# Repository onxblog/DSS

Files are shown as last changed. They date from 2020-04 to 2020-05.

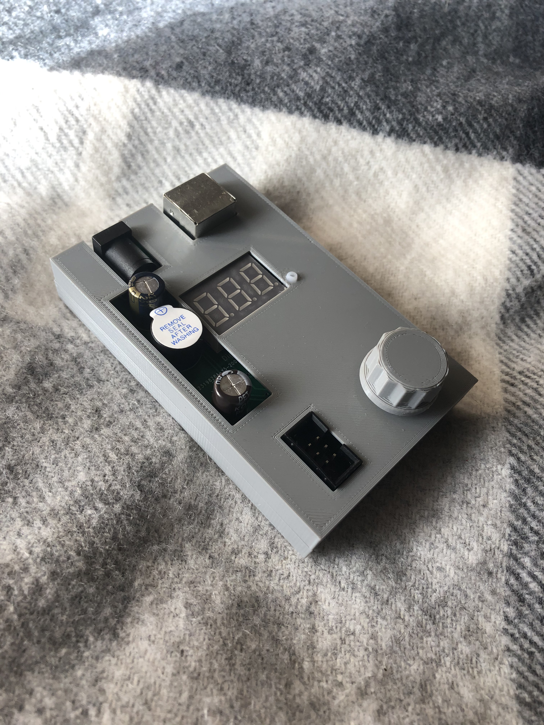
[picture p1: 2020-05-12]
Complit_images/IMG_0456.jpg

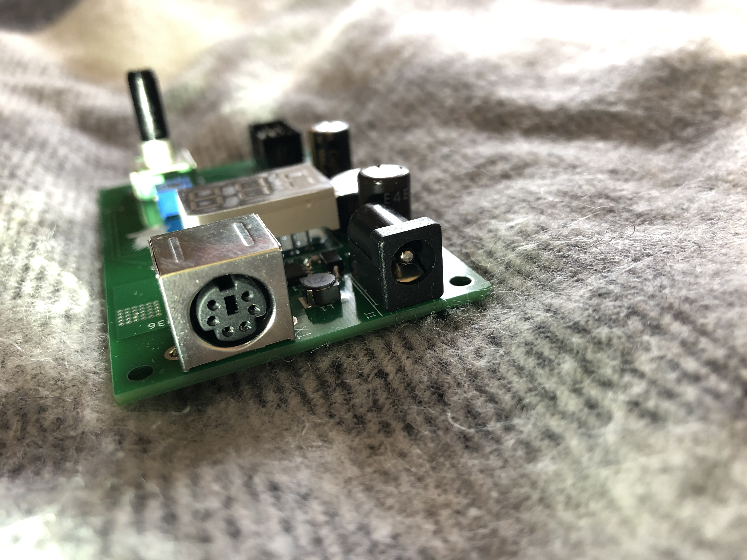
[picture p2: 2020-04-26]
Complit_images/3.jpg

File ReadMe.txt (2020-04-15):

### ----- Digital Soldering Station ----- ###

This station designed in Ukraine and in code have Ukrainian annotation.
Digital Soldering Station (next DSS) designed for iron solder HAKKO 936
Compatible with Lukey 868 852D+ 936+ irons and many others builded on ceramic HAKKO A1321 part.  
DSS have 3 digit led display, buzzer, soft start, programm detector activity, user profilies, encoder managment interface. 

SRC coded in CodeVisionAVR
Firmware autor Victor_P Ukraine

### --- Russian
Данная станция создавалась при участии форума радиокот.
Проект получился весьма интересным и очень качественным.
Дабы труды которые были потраченны на создание данной станции не были напрасны.
Я решил выложить исходные коды (любезно предоставленные Виктором П. во всеобщее пользование) 
и все имеющиеся у меня мои наработки по этой станции во всеобщее пользование.
Особая благодарность Виктору П. за разработку прошивки для данной станции.
Автор прошивки более не поддерживает эту версию станции, а занялся новым проектом совмещающим все имеющиеся у него наработки для создания
новой универсальной станции для всех типов паяльников. Поэтому дання версия отныне в руках GitHub комьюнити.
Версия платы разработанная мною в Eagle, расчитана на паяльники с разъемом вида PS2 от компании Lukey.
Рекомендую прочесть инструкцию, что бы увидеть какой огромный функционал имеет дання станция.
Данные паяльники HAKKO 936 по сей день остаются весьма популярны по причине дешевых расходников и наличия медных жал.
И довольно качесивенного 60Ват керамического нагревателя.

Технические характеристики: 
 Диапазон поддерживаемых температур – 80-420°C.
 Алгоритм нагрева – ПИ.
 Таймер дежурного режима и выключения – есть, совмещенный настраиваемый.
 Программный детектор активности паяльника – есть, настраиваемый.
 Количество профилей паяльников – 2.
 Количество предварительно установленных температур от 3 до 8, настраиваемые.
 Программная калибровка – есть.
 Плавный разогрев – есть.

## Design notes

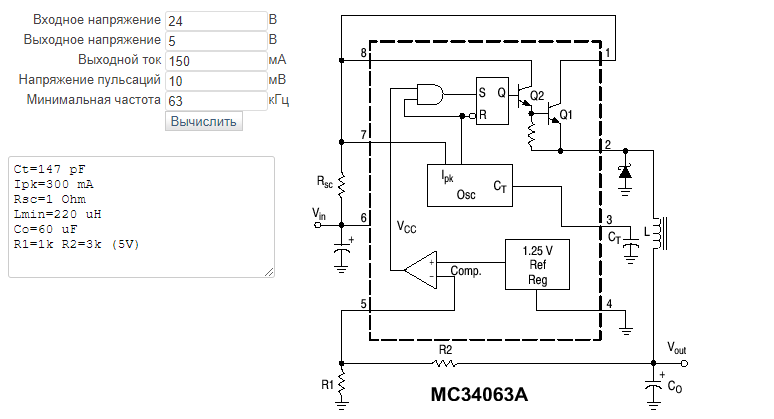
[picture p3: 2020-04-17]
MC34063A.png

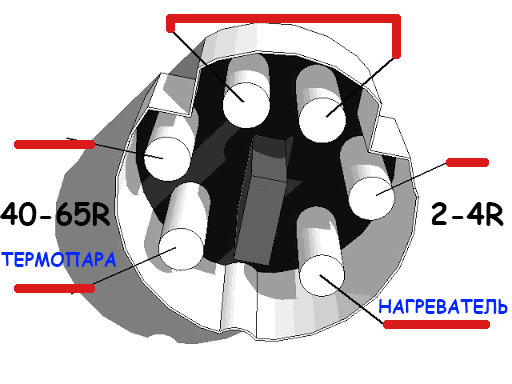
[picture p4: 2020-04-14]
Connector_Lukey_868_852D+_936+.png

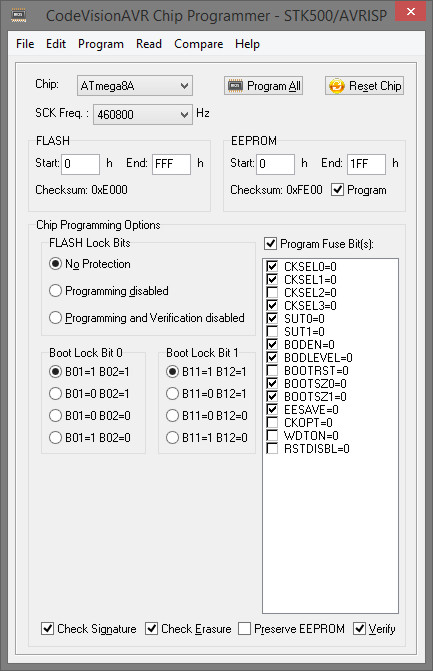
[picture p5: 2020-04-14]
Firmware_bin/fuses.jpg

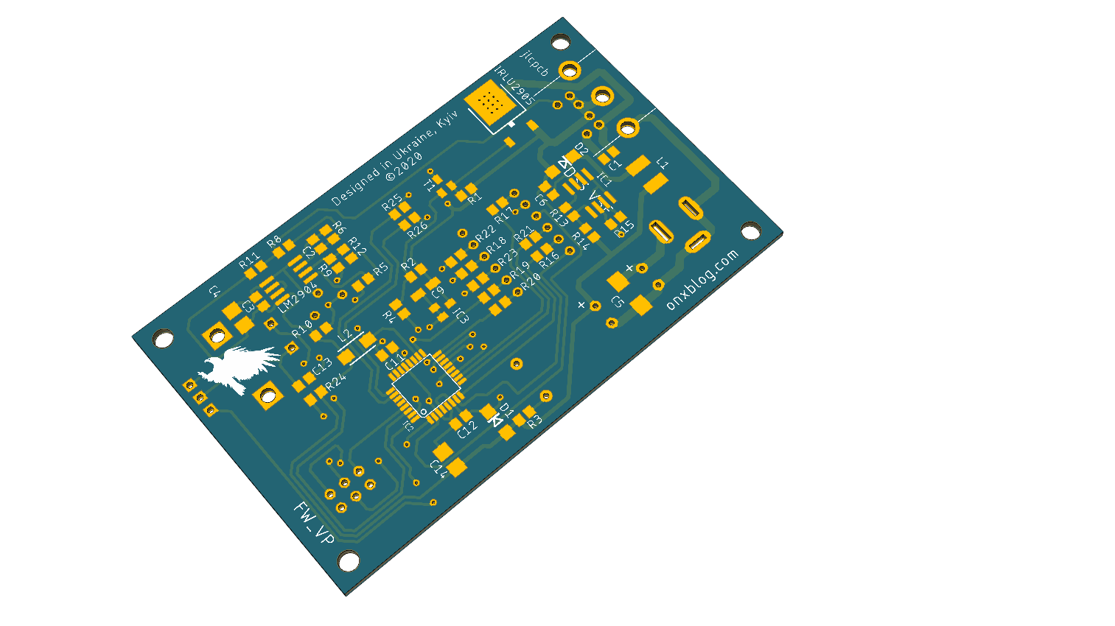
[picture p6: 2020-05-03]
Complit_images/board_img.png

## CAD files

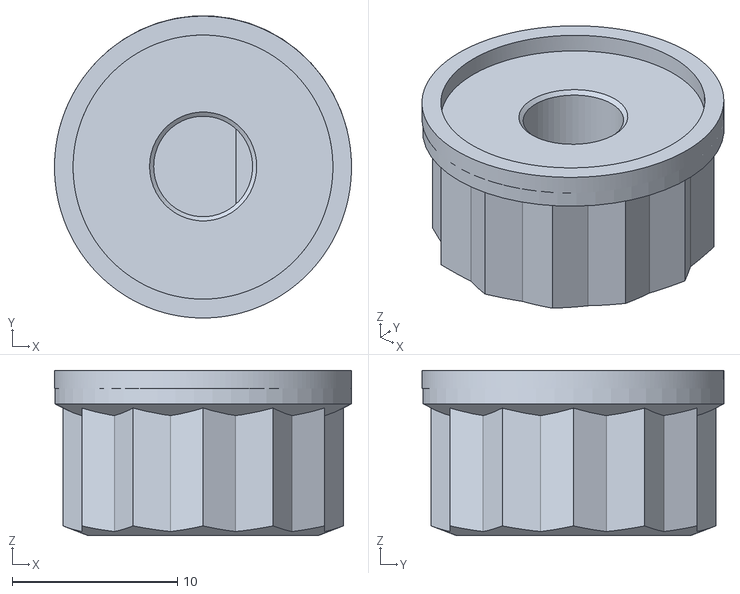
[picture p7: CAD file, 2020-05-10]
3D_Print_case/knob.stl
18.0 x 18.3 x 10.00

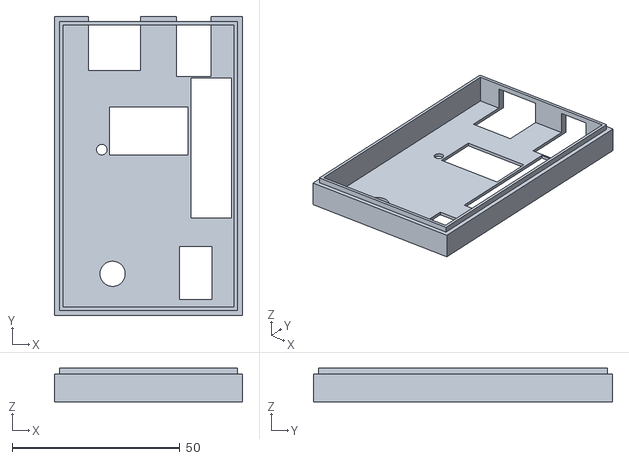
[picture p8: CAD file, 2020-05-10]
3D_Print_case/DSS_UP.stl
56.0 x 89.0 x 10.0

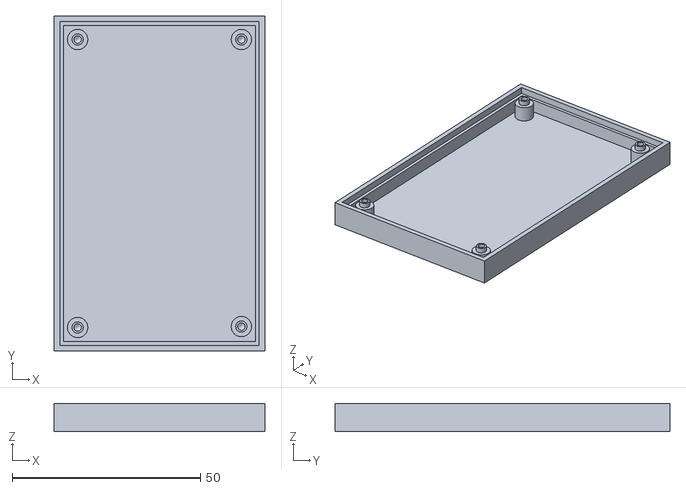
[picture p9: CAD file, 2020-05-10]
3D_Print_case/DSS_DOWN.stl
56.0 x 89.0 x 7.50

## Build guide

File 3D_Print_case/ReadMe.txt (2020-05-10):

Корпус с большим вырезом под конденсаторы и пищалку для разных вариантов плат.
В финале будут вырезы только под конденсаторы что бы сохранить толщину.
Возможен еще вариант без выреза если конденасторы SMD.
Защелки в корпусе не нужны, так как показала практика держится крепко и в таком варианте.

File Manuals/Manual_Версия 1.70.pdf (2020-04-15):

Короткая инструкция по эксплуатации (для версии 1.70, для предыдущих версий некоторые действия будут отличаться).

Внимание! Существует 2 версии этой прошивки, для управления энкодером и для управления кнопками. Не перепутайте нужный вариант при заливке! Версия ПО для управления кнопками мною (и на момент написания инструкции кем-либо еще) не тестировалась.

Управление энкодером:
При первом включении сработает автоопределение типа индикатора. В зависимости от его типа, на индикаторе высветится CAd или CCd при правильном определении типа, либо какой-то бред при неправильном. Если высветился тип индикатора,- нажимаем на энкодер, если высветился мусор,- крутим энкодер в любую сторону, при этом должен высветиться нужный тип и потом нажимаем на энкодер для подтверждения выбора.
- Режим [SM_MAIN_PRM] (первичный режим управления):
После выбора типа индикатора при первом включении и при каждом последующем включении станция 1,5 сек. показывает заданную температуру (изначально это 280 °C), после чего переходит в основной [SM_MAIN_PRM] режим и включает нагрев, светодиодный индикатор засветится красным •. После достижения заданной температуры +-1°C через 4 сек. станция перейдет в режим стабилизации (в котором будет пока температура не выйдет за диапазон установленная +-3°C), индикатор засветится зеленым •.
В зависимости от того, какой приоритетный режим управления выбран в меню настройки CtL, приоритет выбора пресетов температуры (P) или приоритет прямой регулировки температуры (t), вращением энкодера можно либо установить температуру в диапазоне от 80°C до 420°C с шагом в 5°C либо выбрать значение температуры из одного из пресетов, заданное значение автоматически примениться через 4 сек.
Длинным нажатием на энкодер можно записать выставленную температуру в текущую ячейку пресета.
Коротким нажатием на энкодер осуществится переход во вторичный режим управления
[SM_MAIN_SEC].
- Режим [SM_MAIN_SEC] (вторичный режим управления):
Аналогичный первичному, с той разницей, что если для первичного режима выбрано регулирование температуры, то во вторичном будет выбор из пресетов и наоборот.
Выбранное значение применится автоматически через 4 сек. (после чего станция вернется в режим [SM_MAIN_PRM]), или при коротком нажатии на энкодер (при этом также произойдет переход в режим установки времени таймера [SM_TMR_SET]).
Действие для длинного нажатия на кнопку энкодера аналогичное такому для режима
[SM_MAIN_PRM].

Не зависимо для какого режима назначено управление методом выбора пресетов, алгоритм его работы такой: при вращении ручки энкодера по часовой стрелке циклично перебираются активные пресеты температуры, при вращении ручки против часовой стрелки выбирается режим Stb затем OFF. Выбранные значения применятся автоматически через 4 сек.
Переход на следующий уровень меню при выбранных режимах Stb или OFF не производится.
- Режим [SM_TMR_SET] (установка времени таймера):
Вращением энкодера можно установить время срабатывания таймера в диапазоне 0 – 90 мин. С шагом 5 мин. 0 – таймер отключен. Выбранное значение применится автоматически через 4 сек. Коротким нажатием на энкодер значение также применится, но не запишется в EEPROM, т.е. применится только на текущий сеанс работы станции.
Длинное нажатие на энкодер даст тот-же эффект что и автоматическое применение значения через 4 сек.
После любого типа применения установленного значения времени таймера станция вернется в
режим [SM_MAIN_PRM].

- Режим настройки [SM_SUP]:
Вход в режим осуществляется при включении станции с нажатой кнопкой энкодера, при этом отобразится текущая версия программы, после отпускания кнопки появится мигающая надпись SEt. Выход из этого режима в режим [SM_MAIN_PRM] производится длинным нажатием на энкодер. Вращением энкодера влево/вправо (выбор закольцован) можно выбрать один из параметров (подменю) настройки:
- CLb – запуск калибровки, можно производить коротким или длинным нажатием кнопки энкодера;
- Htr – установка коэффициентов ПИД алгоритма нагрева, выбор частоты и максимального заполнения (%) ШИМ нагревателя;
- AdL – установка чувствительности детектора активности паяльника;
- CtL – выбор приоритетного управления и количества активных пресетов температуры;
- Sbt – установка температуры для ждущего режима.
Во всех параметрах настройки кроме CLb, изменение значения подтверждается коротким нажатием на энкодер (автоматический выход из параметра будет через 5 сек. без подтверждения изменения и соответственно без записи нового значения). В подменю Htr и CtL коротким нажатием также осуществляется переход к следующему значению.
- CLb
При запуске калибровки первый раз или при запуске длинным нажатием на энкодер значения коэффициентов начального смещения и усиления, которые передаются в функцию калибровки, будут дефолтными. Т.о. запускать процесс калибровки длинным нажатием на энкодер нужно, если необходимо произвести калибровку заново "с нуля".
При запуске калибровки коротким нажатием на энкодер коэффициенты смещения и усиления не сбрасываются, т.о. можно повторным запуском произвести "докалибровку" (более точную настройку) коэффициентов. Хотя смысла в этом особого нет.
При запуске калибровки на экране появится мигающая комнатная температура (текущая температура холодного паяльника) или сообщение об ошибке, если температура больше 50°C. Необходимо выставить ее верное значение и нажать на энкодер. Пойдет разогрев паяльника до 350°C после стабилизации этого значения индикатор начнет мигать, необходимо измерить реальную температуру паяльника, ввести это значение и нажать на энкодер.
- Htr
Можно установить последовательно коэффициенты ПИД P, I, D, частоту ШИМ Fr, максимальное заполнение ШИМ в % U. При выборе частоты работы ШИМ нагревателя (Fr) индикация частоты отображается в виде буквы H или L для 100Гц и 6.25Гц соответственно.
- CtL
Можно выбрать приоритетное управление (Pc) t – регулировка температуры, P – выбор пресетов и количество активных пресетов (Pn) от 3 до 8.
Выход из любого параметра настройки и калибровки будет в режим [SM_SUP] (SEt на индикаторе).

Управление кнопками:
При первом включении сработает автоопределение типа индикатора. В зависимости от его типа, на индикаторе высветится CAd или CCd при правильном определении типа, либо какой-то бред при неправильном. Если высветился тип индикатора,- нажимаем на "FUNC", если высветился мусор,-нажимаем "+" или "-", при этом должен высветиться нужный тип и потом нажимаем на "FUNC" для подтверждения выбора.
- Режим [SM_MAIN] (основной режим станции):
После выбора типа индикатора при первом включении и при каждом последующем включении станция 1,5 сек. показывает заданную температуру (изначально это 280 °C), после чего переходит в основной [SM_MAIN] режим и включает нагрев, светодиодный индикатор засветится красным •. После достижения заданной температуры +-1°C через 4 сек. станция перейдет в режим стабилизации (в котором будет пока температура не выйдет за диапазон установленная +-3°C), индикатор засветится зеленым •. Коротким нажатием на "+" или "-" можно выбрать одно из предварительно заданных значений температуры (пресетов). Выбранное значение автоматически примениться через 4 сек.

Длинным нажатием (удерживанием) "+" или "-" можно установить температуру в диапазоне от 80°C до 420°C. Первые пять значений регулируемого параметра будут переключаться медленно (задержка 200мс), все остальные (до отпускания кнопки) быстрее (задержка 40мс). Выбранное значение автоматически примениться через 4 сек.
Длинным нажатием на "FUNC" можно записать выставленную температуру в текущую ячейку пресета.
Коротким нажатием на "FUNC" осуществится переход в режим установки времени таймера
[SM_TMR_SET].
- Режим [SM_TMR_SET] (установка времени таймера):
Нажатием на "+" или "-" можно установить время срабатывания таймера в диапазоне 0 – 90 мин. 0 – таймер отключен. Выбранное значение применится автоматически через 4 сек и будет произведен выход в основной режим.
Длинное нажатие на кнопку "FUNC" даст тот-же эффект что и автоматическое применения. Короткое нажатие на кнопку "FUNC" сразу после входа в режим (если значение не изменялось) даст переход в режим настроек [SM_SUP].
- Режим настроек [SM_SUP]:
Вход в режим можно осуществить 2мя способами: при включении станции с нажатой кнопкой "FUNC" (при этом отобразится текущая версия программы), а также из режима [SM_TMR_SET]. При входе в режим появится мигающая надпись SEt. Выход из этого режима в режим [SM_MAIN] производится длинным нажатием на кнопку "FUNC".
Нажатием на "+" или "-" (выбор закольцован) можно выбрать один из параметров (подменю) настройки:
- CLb – запуск калибровки, можно производить коротким или длинным нажатием кнопки "FUNC";
- Htr – установка коэффициентов ПИД алгоритма нагрева, выбор частоты и максимального заполнения (%) ШИМ нагревателя;
- AdL – установка чувствительности детектора активности паяльника;
- Sbt – установка температуры для ждущего режима.
Во всех параметрах настройки кроме CLb, изменение значения подтверждается коротким нажатием на кнопку "FUNC" (автоматический выход из параметра будет через 4 сек. без подтверждения изменения и соответственно без записи нового значения). В подменю Htr коротким нажатием также осуществляется переход к следующему значению.
- CLb
При запуске калибровки первый раз или при запуске длинным нажатием на "FUNC" значения коэффициентов начального смещения и усиления, которые передаются в функцию калибровки, будут дефолтными. Т.о. запускать процесс калибровки длинным нажатием на "FUNC" нужно, если необходимо произвести калибровку заново "с нуля".
При запуске калибровки коротким нажатием на "FUNC" коэффициенты смещения и усиления не сбрасываются, т.о. можно повторным запуском произвести "докалибровку" (более точную настройку) коэффициентов. Хотя смысла в этом особого нет.
При запуске калибровки на экране появится мигающая комнатная температура (текущая температура холодного паяльника) или сообщение об ошибке, если температура больше 50°C. Необходимо выставить ее верное значение и нажать на "FUNC". Пойдет разогрев паяльника до 350°C после стабилизации этого значения индикатор начнет мигать, необходимо измерить реальную температуру паяльника, ввести это значение и нажать на "FUNC".
- Htr
Можно установить последовательно коэффициенты ПИД P, I, D, частоту ШИМ Fr, максимальное заполнение ШИМ в % U. При выборе частоты работы ШИМ нагревателя (Fr) индикация частоты отображается в виде буквы H или L для 100Гц и 6.25Гц соответственно.
Выход из любого параметра настройки и калибровки будет в режим [SM_SUP] (SEt на индикаторе).

Состояние ошибки:

В этом режиме отключается нагрев, станция не реагирует ни на какие действия с энкодером или кнопками, на индикаторе мигает надпись Err, светодиодный индикатор мигает зеленым и красным цветом ••, идет прерывистый звуковой сигнал. Выход из этого состояния возможен только автоматически при пропадании причин возникновения ошибки.
Ошибка может возникать по 2м причинам:
1. Превышение максимальной допустимой температуры (460°C), обычно это говорит об обрыве в цепи измерительного терморезистора или неисправности ОУ или его обвязки;
2. Температура не растет или не падает к заданной в течение 10 сек., может возникать при проблемах как в цепи нагревателя, так и в цепи измерения температуры.

Принцип работы таймера дежурного режима/отключения:
Таймер ведет обратный отсчет только если температура стабилизировалась (зеленый • св. диод). По истечении времени таймера станция перейдет в режим ожидания [SM_STB] (появится мигающая надпись Stb), в котором температура будет поддерживаться на уровне, установленном в меню Sbt. При достижении этой температуры и ее стабилизации (надпись Stb перестанет мигать) таймер запустится снова со значением времени в 2 раза большем выставленного. По истечении этого времени станция перейдет в режим [SM_OFF] (появится надпись OFF),- нагрев выключится. Возврат из режимов [SM_STB] и [SM_OFF] в режим [SM_MAIN] производится любым действием с энкодером (или нажатием на любую кнопку), при этом можно не бояться его крутнуть слишком сильно, изменения установленной температуры не произойдет до прекращения вращения.
Если таймер включен, то на индикаторе в младшем разряде светится точка.
Также таймер сбрасывается детектором активности паяльника (если он включен). Сброс таймера сигнализируется миганием точки в младшем разряде индикатора.

История:

Версия 1.70 (08.11.2014)
добавлено:
- динамическое ограничение максимального заполнения ШИМ;
изменено:
- убрана функция софтстарта (заменена на динамическое ограничение заполнения ШИМ);
- уменьшен выбор частот ШИМ до 2х: 6.25Гц и 100Гц;
- на 56мкс смещено начало АЦ преобразования;
исправлено:
- мелкий баг в управлении;

Версия 1.6 (25.04.2014)
добавлено:
- возможность устанавливать температуру ждущего режима;
- возможность выбирать количество активных пресетов температуры (от 3х до 8ми);
- возможность выбирать первичный тип управления станцией из 2х возможных:
- вращением ручки энкодера установка температуры, после короткого нажатия на энкодер выбор пресета (как было раньше до прошивки 1.5 включительно);
- вращением ручки энкодера выбор пресета, после короткого нажатия на энкодер установка температуры.
- новые пункты меню в режиме настроек;
- возможность принудительно перевести станцию в режим ожидания или выкл.
изменено:
- длительность софтстарта увеличена с 10 секунд до 12 (40 шагов по 300мс), максимальное заполнение ШИМ с 33% до 50%;
- максимальная температура, при которой включается софтстарт увеличена с 60°C до 65°C;
- подменю настройки PId и PFr объединены в одно Htr;
- много изменений в алгоритме управления;
исправлено:

- всякие мелочи;

Версия 1.5 (21.04.2014)
добавлено:
- при включении с нажатой кнопкой энкодера (входе в режим настроек) сначала отображается номер версии прошивки (при первом включении, если не верно определился тип индикатора, покажет мусор);
- выбор частоты ШИМ нагревателя из 3х вариантов: 15.625Гц, 62.5Гц, 250Гц;
изменено:
- температура в ждущем режиме увеличена до 120°C;
- период запуска ПИД алгоритма нагрева не синхронизирован с АЦ преобразованием и составляет 200мс;
- алгоритм измерения и отображения температуры;
- функция автоопределения типа индикатора;
- время перехода из ждущего режима в выкл. теперь в 2 раза больше установленного для перехода в ждущий режим;
- функция софтстарта, теперь софтстарт длится 10 сек (40 шагов по 250мкс);
- алгоритм индикации для разных типов индикаторов;
- в ШИМ нагревателя уменьшено количество ступеней регулировки с 1024 до 250; исправлено:
- проблема с калибровкой в версии 1.41;

Версия 1.41 (24.06.2013)
добавлено:
- вход в режим калибровки по длинному нажатию на энкодер (со сбросом калибровочных коэффициентов);
изменено:
- масштабы коэффициентов ПИД алгоритма нагрева;
исправлено:
- при включении станции показывается установленная температура, а не 000;
- убраны звуковые сигналы, которые могли возникать при определенных условиях, когда станция находилась в режиме калибровки после стабилизации "верхней" температуры 350°C.

Версия 1.4 (25.05.2013)
добавлено:
- сторожевая собака на 1с;
- подтверждение автовыбора типа индикатора коротким нажатием на энкодер и возможность задать вручную при ошибке автовыбора;
- параметр настройки AdL – чувствительность детектора активности паяльника 0-95 (большее значение – меньшая чувствительность, 0 - детектор выключен);
изменено:
- замеры температуры сделаны в перерывах между импульсами ШИМ нагревателя;
- полностью изменен ПИД алгоритм нагрева, применен дифференциальный вариант по совету и при поддержке Леонида Ивановича;
- полностью изменен детектор активности паяльника, применен алгоритм Леонида Ивановича;
- шаг изменения значения таймера изменен с 10 на 5 минут;
- таймер работает только в режиме стабилизации температуры (зеленый светодиод), во время нагрева/остывания нет;
- выход из любого параметра настройки (с сохранением – коротким нажатием, без сохранения – ждем 4с) происходит в режим настройки (SEt), выход из режима настройки теперь длинным нажатием на энкодер;
исправлено:
- убрана реакция на последнюю нажатую кнопку в режиме ошибки;
- теперь при переходе в режим установки времени таймера, если перед этим была выбрана температура из пресета, она таки выбирается;

- при длинном нажатии на энкодер в режиме выбора пресета или времени таймера теперь значение записывается, выбирается и производится выход в основной режим.

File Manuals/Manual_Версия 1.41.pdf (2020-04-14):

Короткая инструкция по эксплуатации (для версии 1.41, для предыдущих версий некоторые действия буду отличаться).

При первом включении сработает автоопределение типа индикатора. В зависимости от его типа, на индикаторе высветится CAd или CCd при правильном определении типа, либо какой-то бред при неправильном. Если высветился тип индикатора,- нажимаем на энкодер, если высветился мусор,- крутим энкодер (в любую сторону), при этом должен высветиться нужный тип и потом нажимаем на энкодер для подтверждения выбора.

- Режим [SM_MAIN] (основной):
После выбора типа индикатора при первом включении и при каждом последующем включении станция 1,5 сек. показывает заданную температуру (изначально это 280 °C), после чего переходит в основной [SM_MAIN] режим и включает нагрев (в зависимости от текущей температуры, если она меньше 60°C, включится софтстарт), св.диод засветится красным •. После достижения заданной температуры +-1°C через 4 сек. станция перейдет в режим стабилизации (в котором будет пока температура не выйдет за диапазон установленная +-3°C), св.диод засветится зеленым •.
Вращением энкодера можно задать температуру в диапазоне от 80°C до 420°C с шагом в 5°C, заданное значение автоматически примениться через 3 сек.
Длинным нажатием на энкодер можно записать выставленную температуру в текущую ячейку пресета (всего их 5).
Коротким нажатием на энкодер осуществится переход в режим выбора пресетов [SM_TPS_SET].
- Режим [SM_TPS_SET] (выбор предварительно записанных значений температуры):
Вращением энкодера можно выбрать одно из 5 предварительно установленных значений температуры. Выбор закольцован. Выбранное значение применится автоматически через 3 сек. (после чего станция вернется в режим [SM_MAIN]), или при коротком нажатии на энкодер (при этом также произойдет переход в режим установки времени таймера [SM_TMR_SET]).
При длинном нажатии на энкодер буде произведена запись предварительно выставленной температуры в режиме [SM_MAIN] в текущую позицию с заменой существующего значения (действие аналогичное такому-же в режиме [SM_MAIN], только здесь видно вместо какой температуры запишется выбранная).
- Режим [SM_TMR_SET] (установка времени таймера):
Вращением энкодера можно установить время срабатывания таймера в диапазоне 0 – 90 мин. С шагом 5 мин. 0 – таймер отключен. Выбранное значение применится автоматически через 3 сек. Коротким нажатием на энкодер значение также применится, но не запишется в EEPROM, т.е. применится только на текущий сеанс работы станции.
Длинное нажатие на энкодер даст тот-же эффект что и автоматическое применение значения через 3 сек.
После любого типа применения установленного значения времени таймера станция вернется в режим [SM_MAIN].
Немного о самом таймере.
Таймер ведет обратный отсчет только если температура стабилизировалась (зеленый • св. диод). По истечении времени таймера станция перейдет в режим ожидания [SM_STB] (появится мигающая надпись Stb), в котором температура будет поддерживаться на уровне 80°C. При достижении этой температуры и ее стабилизации (надпись Stb перестанет мигать) таймер запустится снова с значением времени в 2 раза меньшим выставленного. По истечении этого времени станция перейдет в режим [SM_OFF] (появится надпись OFF),- нагрев выключится. Возврат из режимов [SM_STB] и [SM_OFF] в режим [SM_MAIN] производится любым действием с энкодером, при этом можно не бояться его крутнуть слишком сильно, изменения установленной температуры не произойдет до прекращения вращения. Если таймер включен, то на индикаторе в младшем разряде светится точка.
Таймер сбрасывается любым действием с энкодером, а также детектором активности паяльника (если он включен). Сброс таймера сигнализируется миганием точки в младшем разряде индикатора.

- Режим настройки [SM_SUP]:
Вход в режим осуществляется при включении станции с нажатой кнопкой энкодера, при этом появится мигающая надпись SEt . Выход из этого режима в режим [SM_MAIN] производится длинным нажатием на энкодер.
Вращением энкодера влево/вправо (выбор закольцован) можно выбрать один из параметров настройки:
- AdL – чувствительность детектора активности паяльника;
- PId – установка коэффициентов ПИД алгоритма нагрева;
- CLb – запуск калибровки, можно производить коротким или длинным нажатием кнопки энкодера. В параметрах настройки AdL и PId изменение значения подтверждаем коротким нажатием на энкодер (автоматический выход из параметра будет через 3 сек. без подтверждения изменения и соответственно без записи нового значения). В параметре PId коротким нажатием также осуществляется переход к следующему значению.
При запуске калибровки первый раз или при запуске длинным нажатием на энкодер значения коэффициентов начального смещения и усиления, которые передаются в функцию калибровки, будут дефолтными. Т.о. запускать процесс калибровки длинным нажатием на энкодер нужно, если необходимо произвести калибровку заново "с нуля".
При запуске калибровки коротким нажатием на энкодер коэффициенты смещения и усиления не сбрасываются, т.о. можно повторным запуском произвести "докалибровку" (более точную настройку) коэффициентов. Хотя смысла в этом особого нет.
При запуске калибровки (CLb) на экране появится мигающая комнатная температура (текущая температура холодного паяльника) или сообщение об ошибке, если температура больше 50°C. Необходимо выставить ее верное значение и нажать на энкодер. Пойдет разогрев паяльника до 350°C после стабилизации этого значения индикатор начнет мигать, необходимо измерить реальную температуру паяльника, ввести это значение и нажать на энкодер.
Выход из любого параметра настройки и калибровки будет в режим [SM_SUP] (SEt на индикаторе).
- Режим [Err] (состояние ошибки):
В этом режиме отключается нагрев, станция не реагирует ни на какие действия с энкодером, на индикаторе мигает надпись Err, св. диод мигает зеленым и красным цветом ••, идет прерывистый звуковой сигнал. Выход из этого состояния возможен только автоматически при пропадании причин возникновения ошибки.
Ошибка может возникать по 2м причинам:
1. Превышение максимальной допустимой температуры (460°C), обычно это говорит об обрыве в цепи измерительного терморезистора или неисправности ОУ или его обвязки;
2. Температура не растет или не падает к заданной в течение 10 сек., может возникать при проблемах как в цепи нагревателя так и в цепи измерения температуры.

Версия 1.41 (24.06.2013)
добавлено:
- вход в режим калибровки по длинному нажатию на энкодер (со сбросом калибровочных коэффициентов);
изменено:
- масштабы коэффициентов ПИД алгоритма нагрева;
исправлено:
- при включении станции показывается установленная температура, а не 000;
- убраны звуковые сигналы, которые могли возникать при определенных условиях, когда станция находилась в режиме калибровки после стабилизации "верхней" температуры 350°C.

Версия 1.4 (25.05.2013)
добавлено:
- сторожевая собака на 1с;
- подтверждение автовыбора типа индикатора коротким нажатием на энкодер и возможность задать вручную при ошибке автовыбора;
- параметр настройки AdL – чувствительность детектора активности паяльника 0-95 (большее значение – меньшая чувствительность, 0 - детектор выключен);
изменено:
- замеры температуры сделаны в перерывах между импульсами ШИМ нагревателя;
- полностью изменен ПИД алгоритм нагрева, применен дифференциальный вариант по совету и при поддержке Леонида Ивановича;
- полностью изменен детектор активности паяльника, применен алгоритм Леонида Ивановича;
- шаг изменения значения таймера изменен с 10 на 5 минут;
- таймер работает только в режиме стабилизации температуры (зеленый светодиод),
во время нагрева/остывания нет;
- выход из любого параметра настройки (с сохранением – коротким нажатием, без сохранения – ждем 4с) происходит в режим настройки (SEt), выход из режима настройки теперь длинным нажатием на энкодер;
исправлено:
- убрана реакция на последнюю нажатую кнопку в режиме ошибки;
- теперь при переходе в режим установки времени таймера, если перед этим была выбрана температура из пресета, она таки выбирается ;
- при длинном нажатии на энкодер в режиме выбора пресета или времени таймера теперь значение записывается, выбирается и производится выход в основной режим.

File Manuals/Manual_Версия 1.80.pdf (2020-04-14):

### Инструкция по эксплуатации версия 1.80 от 05.04.2016

Технические характеристики:
- Диапазон поддерживаемых температур – 80-420°C;
- Алгоритм нагрева – ПИ;
- Таймер дежурного режима и выключения – есть, совмещенный настраиваемый;
- Поддержка вибродатчика – есть;
- Программный детектор активности паяльника – есть, настраиваемый;
- Количество профилей паяльников – 2;
- Количество предварительно установленных температур от 3 до 8, настраиваемые;
- Программная калибровка – есть;
- Плавный разогрев – есть, для паяльников 0 типа.

Внимание! Эта прошивка предназначена для управления энкодером. Последняя на данный момент версия ПО для управления кнопками FW_VP_v1.701_KEY от 12.05.2015.
Обе эти версии мною лично не тестировались.

Включение
При первом включении сработает автоопределение типа индикатора. В зависимости от его
типа, на индикаторе высветится | или | при правильном определении типа, либо какой-то
бред при неправильном. Если высветился тип индикатора, - нажимаем на энкодер, если высветился мусор, - крутим энкодер в любую сторону, при этом должен высветиться нужный тип и потом нажимаем на энкодер для подтверждения выбора.

После выбора типа индикатора при первом включении и при каждом последующем включении станция 1,5 сек. показывает заданную температуру (изначально это °C), после чего переходит в основной режим и включает нагрев, светодиодный индикатор засветится красным •. После достижения заданной температуры +-1°C через 2 сек. станция перейдет в режим стабилизации, в котором будет находиться пока температура не выйдет за диапазон удержания температуры (установленная +-20°C), индикатор засветится зеленым •.

Основной режим
В этом режиме можно выбрать одну из предварительно установленных температур (пресетов), установить и сохранить в пресет любую температуру, установить время таймера
дежурного режима/отключения, а также перейти в дежурный режим ( | ), режим настроек ( | )
или выключить нагрев ( | ).

Выбор пресетов.
Вращением энкодера можно выбрать значение температуры из одного из пресетов, а также при вращении энкодера против часовой стрелки после прохождения пресета с наименьшим
порядковым номером можно выбрать переход в дежурный режим ( | ) или выключить нагрев
( | ).
Коротким нажатием на энкодер осуществится переход в режим непосредственной установки температуры.
Двумя короткими нажатиями на энкодер осуществится переход к регулировке времени таймера перехода в дежурный режим и отключения.
Длинным нажатием на энкодер осуществится переход в режим настроек ( ).

Установка температуры.
Вращением энкодера можно установить температуру с шагом +-5°C.
Коротким нажатием на энкодер можно перейти к регулировке времени таймера перехода в дежурный режим и отключения.
Длинным нажатием на энкодер осуществляется запись выбранной температуры в текущий пресет.

Установка времени таймера.
Вращением энкодера можно установить время срабатывания таймера перехода в дежурный режим и отключения в диапазоне 0 – 90 мин. с шагом 5 мин. 0 – таймер отключен. Длинное нажатие на энкодер даст тот-же эффект что и автоматическое применение значения через 4 сек.

После любых изменений значений температуры или времени таймера в этом режиме, заданное значение автоматически примениться через 4 сек. Можно применить значение принудительно коротким нажатием на энкодер, при этом также будет осуществлен переход к регулировке следующего параметра. После любого типа применения установленного значения времени таймера станция вернется в режим выбора пресетов.

Работа таймера отключения/дежурного режима
По истечении времени таймера станция перейдет в режим ожидания (появится мигающая надпись ), в котором температура будет поддерживаться на уровне, установленном в соответствующем пункте меню настроек. При достижении этой температуры и ее стабилизации (надпись перестанет мигать) таймер запустится снова со значением времени в 2 раза большем выставленного. По истечении этого времени станция выключит нагрев паяльника (появится надпись ). Возврат из режимов ожидания и выключения в основной режим производится вращением либо нажатием на кнопку энкодера или при срабатывании вибродатчика в паяльнике.
Перейти в дежурный режим или отключить нагрев паяльника можно принудительно
повернув ручку энкодера против часовой стрелки до появления надписи | и затем | .
Переход в режим произойдет через 4 сек.
Если таймер включен, то на индикаторе в младшем разряде светится точка.
Таймер сбрасывается вращением либо нажатием на кнопку энкодера, при срабатывании датчика вибрации, а также детектором активности паяльника (если включен). Сброс таймера сигнализируется миганием точки в младшем разряде индикатора.

Режим настроек
Попасть в этот режим можно двумя способами, - включением станции с зажатой кнопкой энкодера или длинным нажатием на кнопку энкодера в основном режиме.
В этом меню есть шесть пунктов:
- - выбор типа паяльника;
- - установка коэффициентов П и И алгоритма нагрева;
- - калибровка;
- - установка порога чувствительности детектора активности;
- - установка количества пресетов температуры;
- - установка температуры дежурного режима;

Переключение между пунктами производится вращением энкодера, вход коротким нажатием. Запись значения с выходом в меню настроек также производится коротким нажатием. Автоматический выход в режим настроек без сохранения изменений будет через 4 сек.

- Тип паяльника выбирается один из: 0 – обычный, 1 – Т12.
- Значения коэффициентов P и I устанавливаются в диапазоне 0…99, переключение между коэффициентами коротким нажатием.
- При запуске калибровки первый раз или при запуске длинным нажатием на энкодер значения коэффициентов начального смещения и усиления, которые передаются в функцию калибровки, будут дефолтными. Т.о. запускать процесс калибровки длинным нажатием на энкодер нужно, если необходимо произвести калибровку заново "с нуля".
При запуске калибровки коротким нажатием на энкодер коэффициенты смещения и усиления не сбрасываются, т.о. можно повторным запуском произвести "докалибровку" (более точную настройку) коэффициентов. Хотя смысла в этом особого нет.
При запуске калибровки на экране появится мигающая комнатная температура (текущая температура холодного паяльника) или сообщение об ошибке, если температура больше 50°C. Необходимо выставить ее верное значение и нажать на энкодер. Пойдет разогрев паяльника до 350°C для обычных паяльников и до 300°C для Т12, после стабилизации этого значения индикатор начнет мигать, необходимо измерить реальную температуру паяльника, ввести это значение и нажать на энкодер.
- Значение порога чувствительности детектора активности паяльника устанавливается в диапазоне 0…95. Чем больше значение, тем менее чувствителен детектор, 0 выключает влияние детектора активности на сброс таймера.
- Количество активных пресетов температуры можно установить от 3 до 8 штук.
- Температура дежурного режима устанавливается в диапазоне 80…160°C.

Выход из режима установок производится длинным нажатием на энкодер, когда на индикаторе надпись .

Режим ошибки
Если температура паяльника превышала максимально допустимую (460°C) плюс 10°C в течении 0.5 сек. или не было нагрева/охлаждения паяльника в течении 10 сек., станция переходит
в режим ошибки, соответственно | или | .
В этом режиме отключается нагрев, станция не реагирует ни на какие действия с энкодером, на индикаторе мигает надпись , светодиодный индикатор мигает зеленым и красным цветом ••, идет прерывистый звуковой сигнал. Выход из этого состояния возможен только автоматически при пропадании причин возникновения ошибки.

История:

Версия 1.80 (05.04.2016)
добавлено:
- возможность выбора одного из 2х типов паяльников;
- поддержка датчика вибрации, подключается на порт PC1; изменено:
- убран выбор частот ШИМ, оставлена только 100Гц;
- функция нагрева теперь ПИ;
- максимальное заполнение ШИМ теперь 95% и не регулируется;
- убрана возможность выбирать основной режим управления; исправлено:
- убраны старые глюки, добавлены новые;

Версия 1.70 (08.11.2014)
добавлено:
- динамическое ограничение максимального заполнения ШИМ;
изменено:
- убрана функция софтстарта (заменена на динамическое ограничение заполнения ШИМ);
- уменьшен выбор частот ШИМ до 2х: 6.25Гц и 100Гц;
- на 56мкс смещено начало АЦ преобразования;
исправлено:
- мелкий баг в управлении;

Версия 1.6 (25.04.2014)
добавлено:
- возможность устанавливать температуру ждущего режима;
- возможность выбирать количество активных пресетов температуры (от 3х до 8ми);
- возможность выбирать первичный тип управления станцией из 2х возможных:
- вращением ручки энкодера установка температуры, после короткого нажатия на энкодер выбор пресета (как было раньше до прошивки 1.5 включительно);
- вращением ручки энкодера выбор пресета, после короткого нажатия на энкодер установка температуры.
- новые пункты меню в режиме настроек;
- возможность принудительно перевести станцию в режим ожидания или выкл. изменено:
- длительность софтстарта увеличена с 10 секунд до 12 (40 шагов по 300мс), максимальное заполнение ШИМ с 33% до 50%;
- максимальная температура, при которой включается софтстарт увеличена с 60°C до 65°C;
- подменю настройки | и | объединены в одно | ;
- много изменений в алгоритме управления;
исправлено:
- всякие мелочи;

Версия 1.5 (21.04.2014)
добавлено:
- при включении с нажатой кнопкой энкодера (входе в режим настроек) сначала отображается номер версии прошивки (при первом включении, если не верно определился тип индикатора, покажет мусор);
- выбор частоты ШИМ нагревателя из 3х вариантов: 15.625Гц, 62.5Гц, 250Гц;

изменено:
- температура в ждущем режиме увеличена до 120°C;
- период запуска ПИД алгоритма нагрева не синхронизирован с АЦ преобразованием и составляет 200мс;
- алгоритм измерения и отображения температуры;
- функция автоопределения типа индикатора;
- время перехода из ждущего режима в выкл. теперь в 2 раза больше установленного для перехода в ждущий режим;
- функция софтстарта, теперь софтстарт длится 10 сек (40 шагов по 250мкс);
- алгоритм индикации для разных типов индикаторов;
- в ШИМ нагревателя уменьшено количество ступеней регулировки с 1024 до 250; исправлено:
- проблема с калибровкой в версии 1.41;

Версия 1.41 (24.06.2013)
добавлено:
- вход в режим калибровки по длинному нажатию на энкодер (со сбросом калибровочных коэффициентов);
изменено:
- масштабы коэффициентов ПИД алгоритма нагрева;
исправлено:
- при включении станции показывается установленная температура, а не ;
- убраны звуковые сигналы, которые могли возникать при определенных условиях, когда станция находилась в режиме калибровки после стабилизации "верхней" температуры 350°C.

Версия 1.4 (25.05.2013)
добавлено:
- сторожевая собака на 1с;
- подтверждение автовыбора типа индикатора коротким нажатием на энкодер и возможность задать вручную при ошибке автовыбора;
- параметр настройки – чувствительность детектора активности паяльника 0-95 (большее значение – меньшая чувствительность, 0 - детектор выключен);
изменено:
- замеры температуры сделаны в перерывах между импульсами ШИМ нагревателя;
- полностью изменен ПИД алгоритм нагрева, применен дифференциальный вариант по совету и при поддержке Леонида Ивановича;
- полностью изменен детектор активности паяльника, применен алгоритм Леонида Ивановича;
- шаг изменения значения таймера изменен с 10 на 5 минут;
- таймер работает только в режиме стабилизации температуры (зеленый светодиод), во время нагрева/остывания нет;
- выход из любого параметра настройки (с сохранением – коротким нажатием, без сохранения – ждем 4с) происходит в режим настройки ( ), выход из режима настройки теперь длинным нажатием на энкодер;
исправлено:
- убрана реакция на последнюю нажатую кнопку в режиме ошибки;
- теперь при переходе в режим установки времени таймера, если перед этим была выбрана температура из пресета, она таки выбирается;

- при длинном нажатии на энкодер в режиме выбора пресета или времени таймера теперь значение записывается, выбирается и производится выход в основной режим.

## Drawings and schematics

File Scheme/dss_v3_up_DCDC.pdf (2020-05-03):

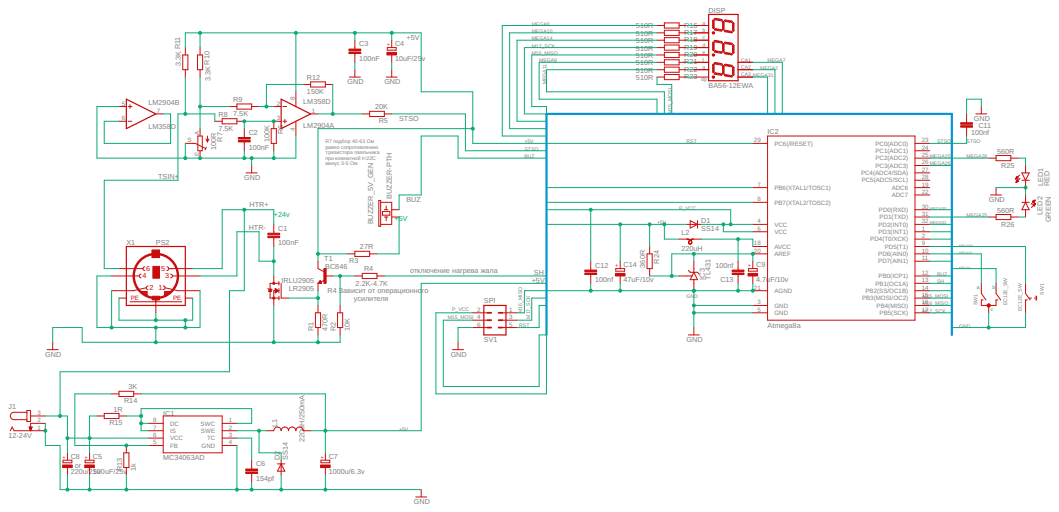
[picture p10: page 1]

HTR-

отключение нагрева жала R4 Зависит от операционного

5 | M17_SCK

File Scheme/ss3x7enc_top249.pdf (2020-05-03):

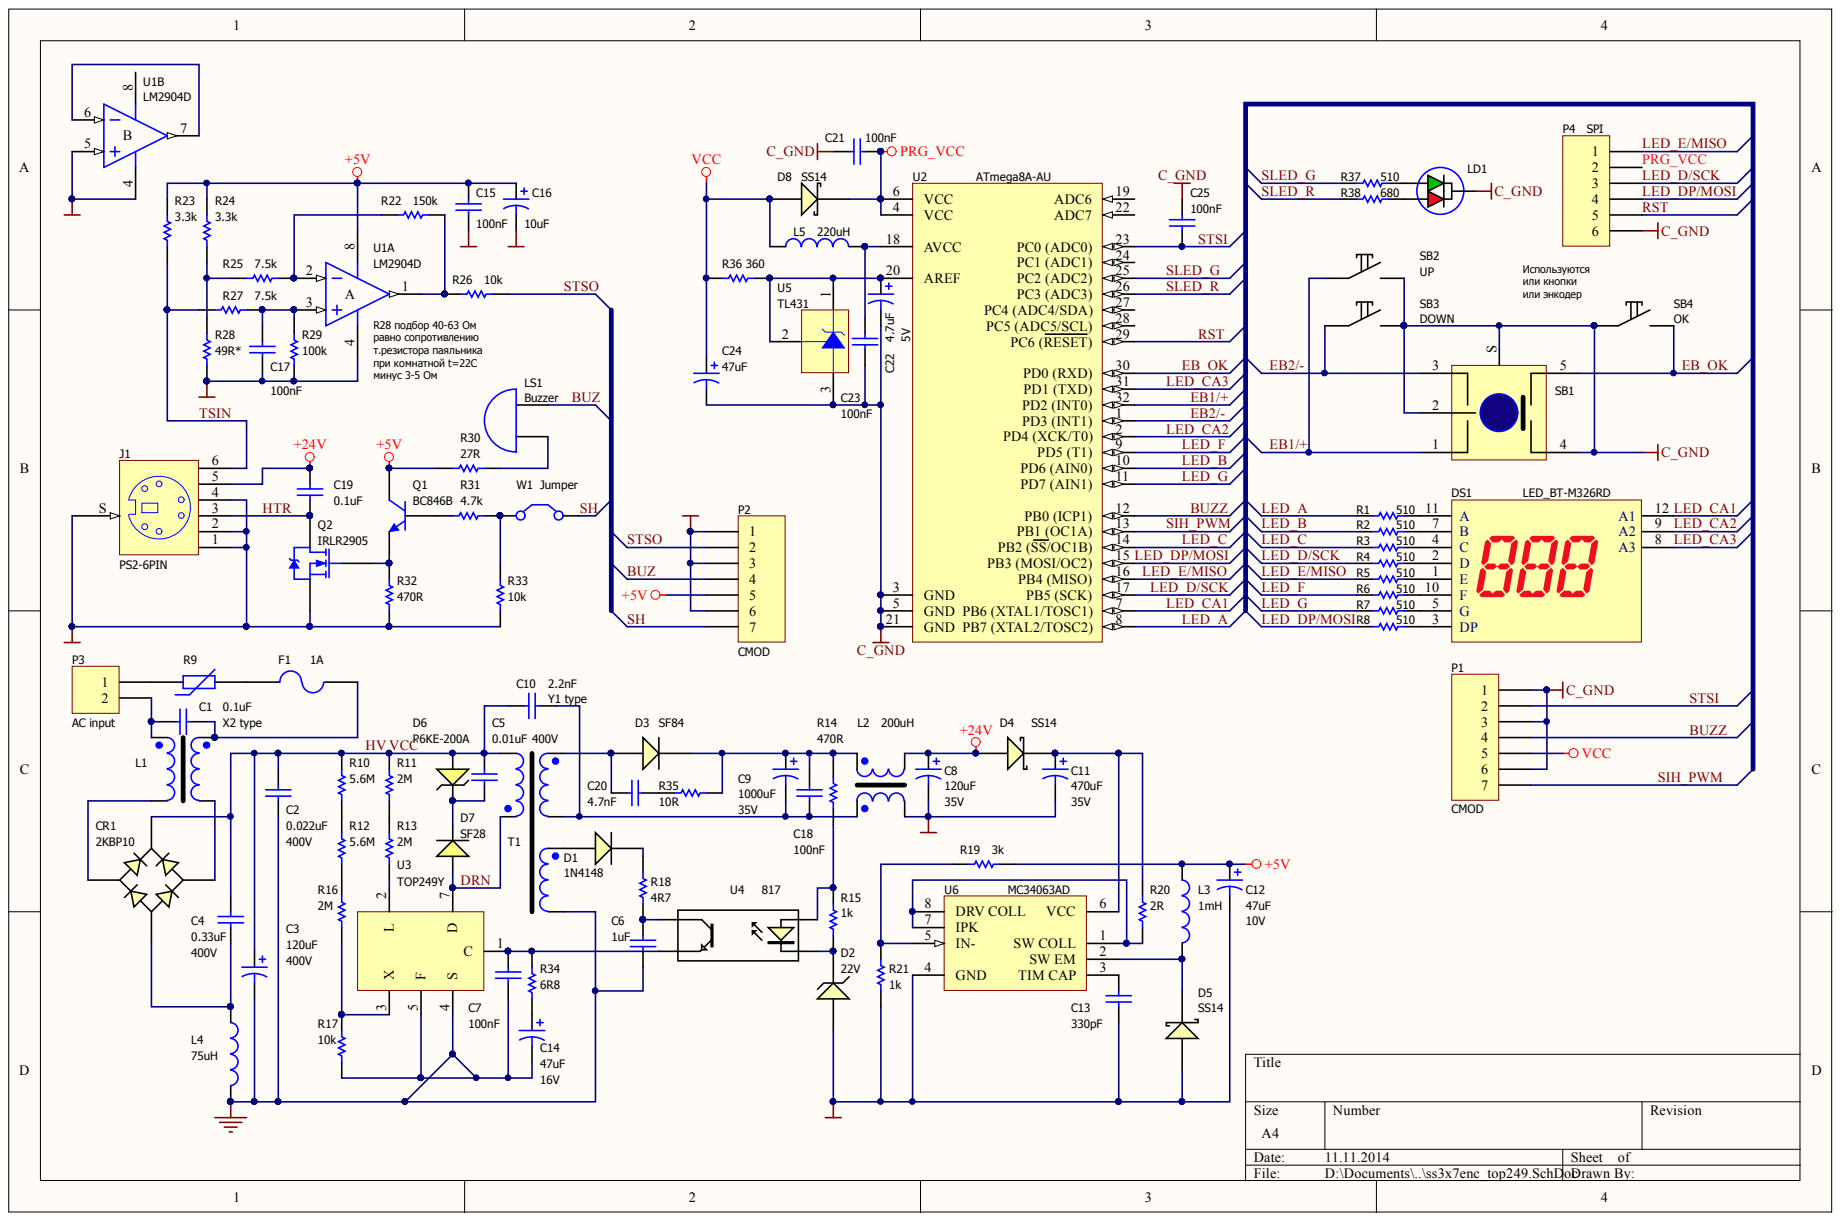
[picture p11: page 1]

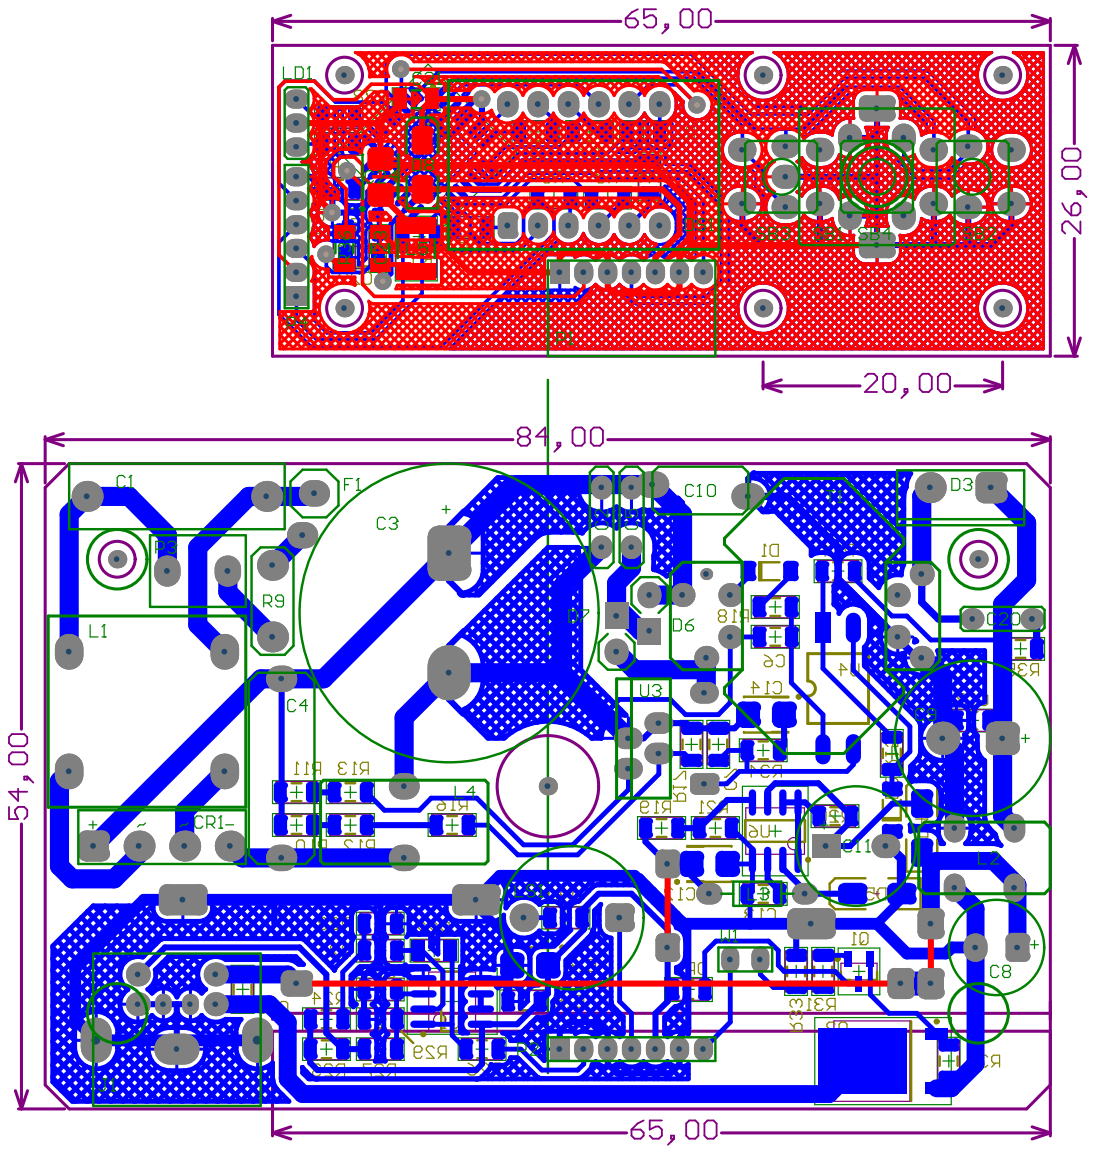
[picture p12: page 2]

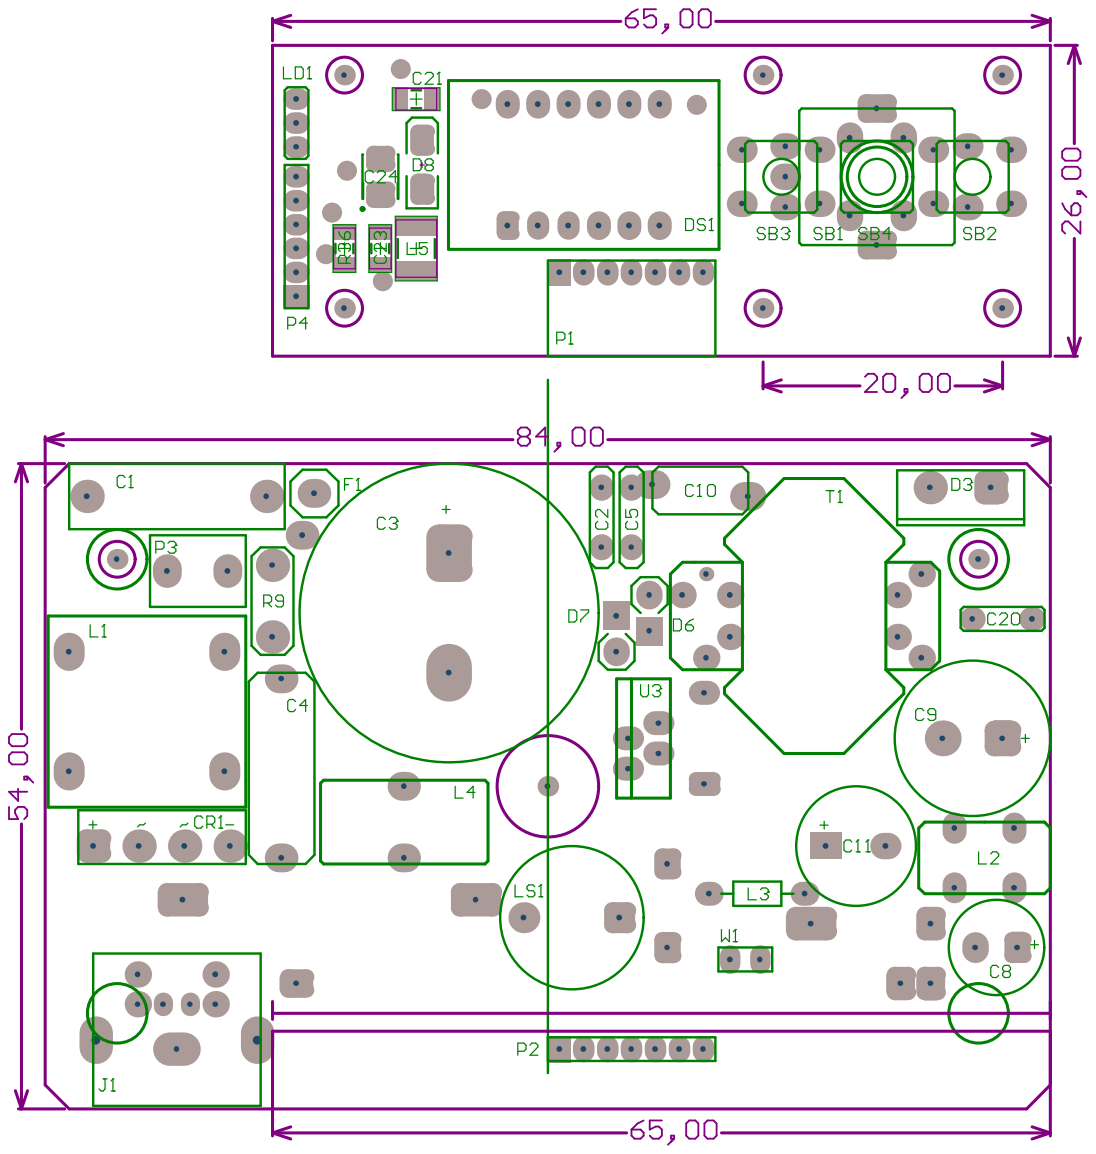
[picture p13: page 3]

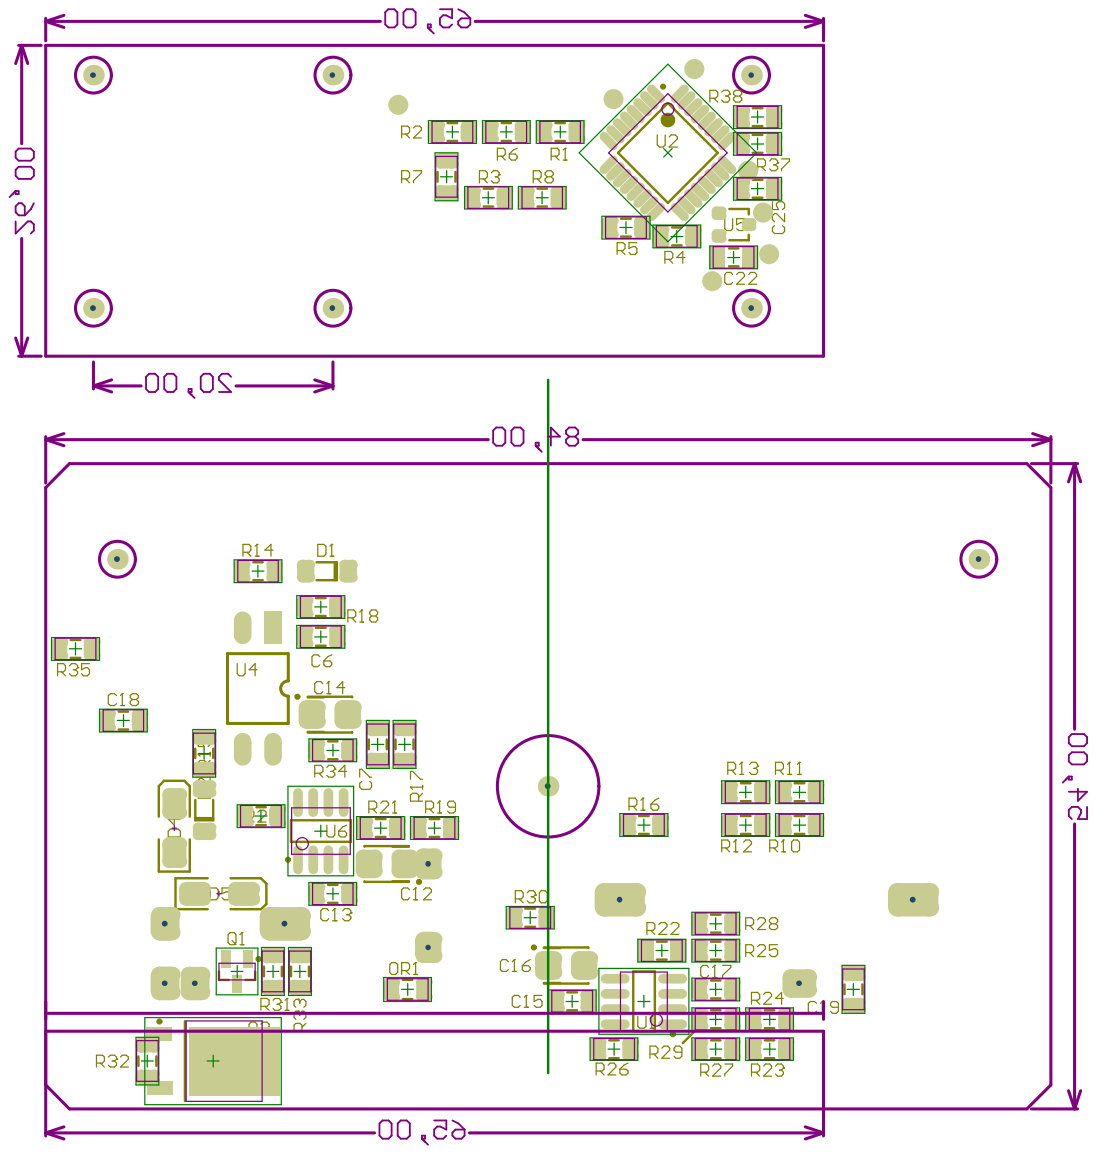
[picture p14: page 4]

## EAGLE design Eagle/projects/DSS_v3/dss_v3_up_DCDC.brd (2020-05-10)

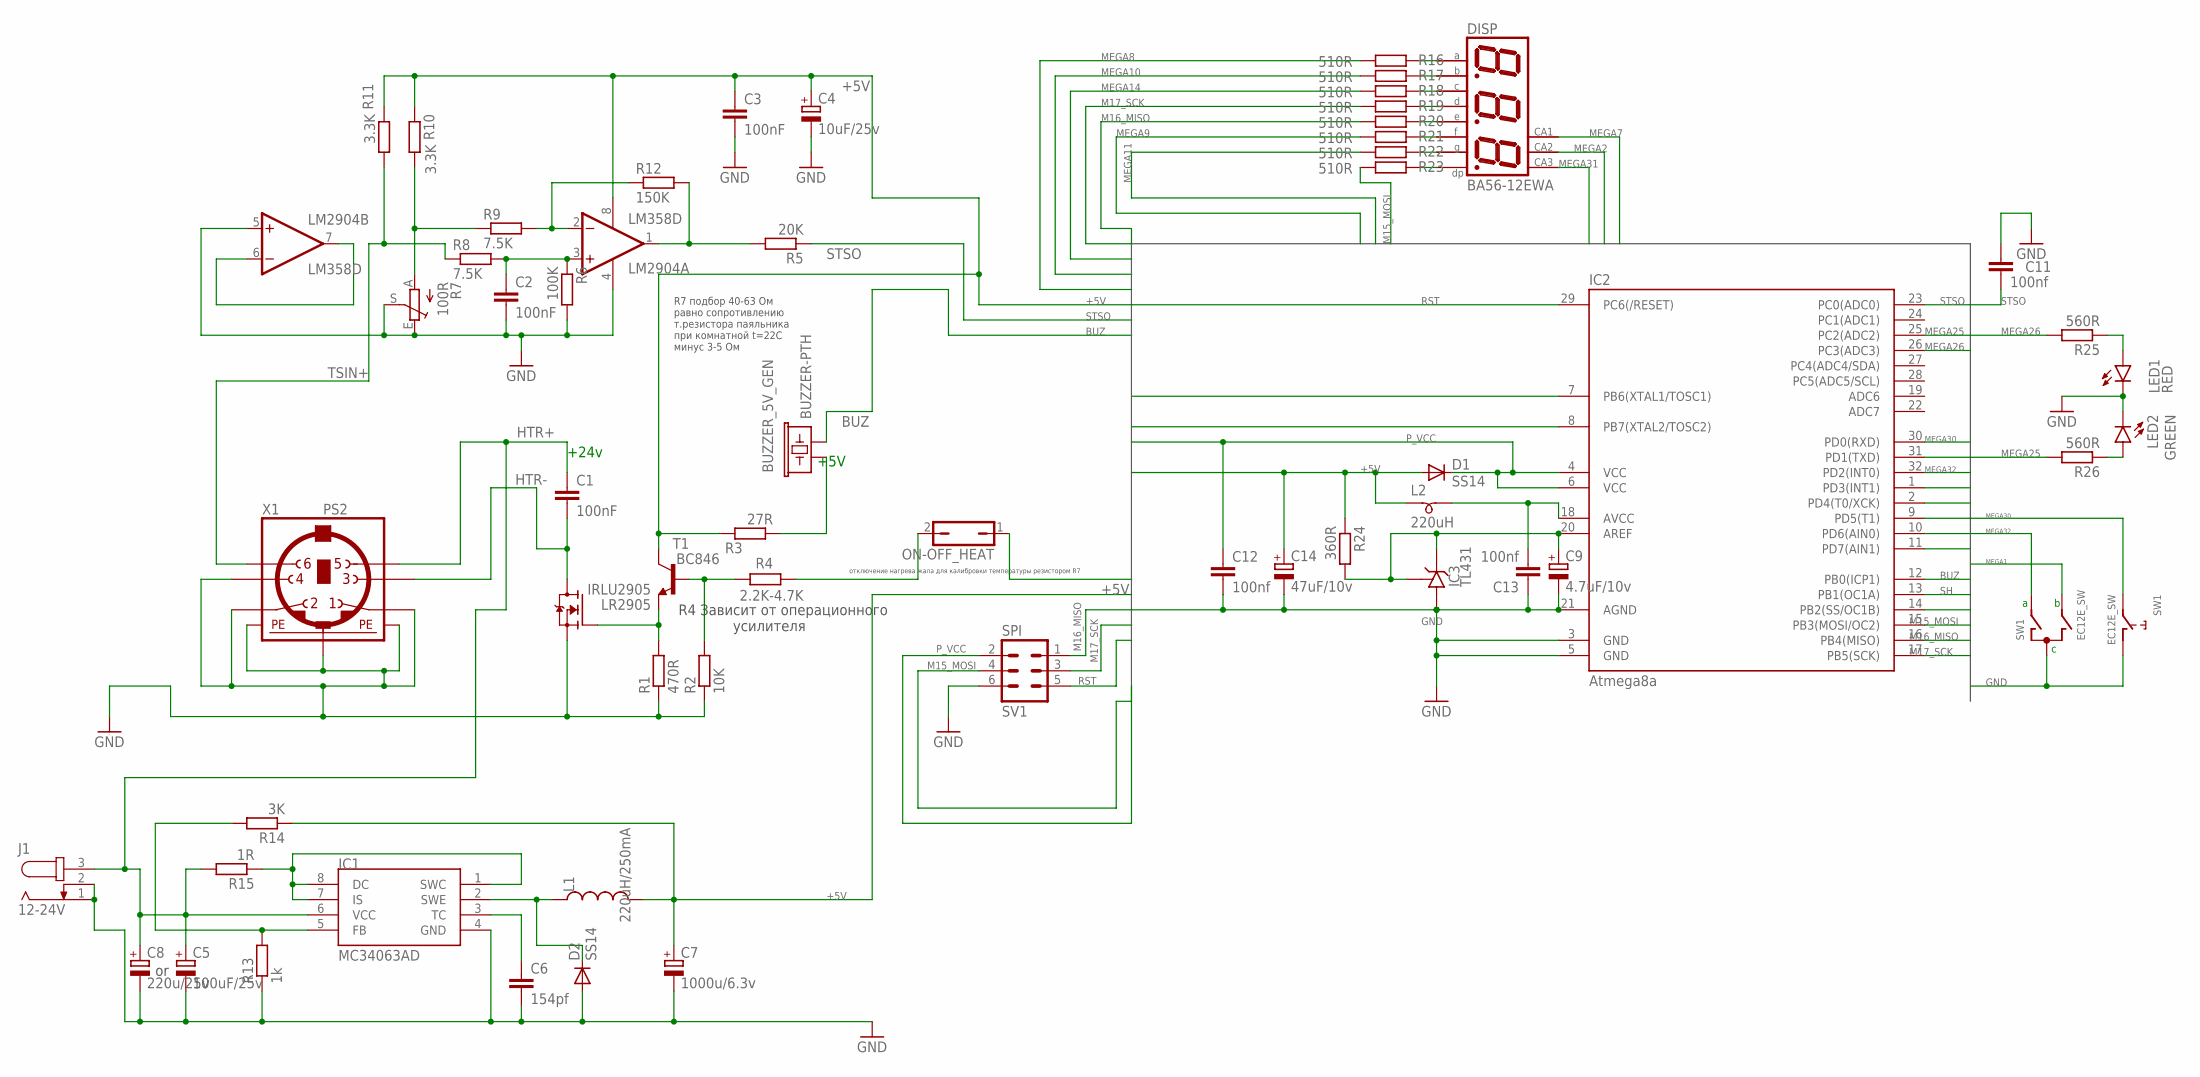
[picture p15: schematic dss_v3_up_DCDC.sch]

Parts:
BUZZER_5V_GEN: BUZZER-PTH; BUZZER-12MM
C1, C2, C3: 100nF; C0805
C4: 10uF/25v; CT3528
C5: 100uF/25v; CT6032
C6: 154pf; C0805
C7: 1000u/6.3v; E3,5-8
C8: 220u/25v; E3,5-8
C9: 4.7uF/10v; CT3216
C11, C12, C13: 100nf; C0805
C14: 47uF/10v; CT3528
D1, D2: SS14; DO214AC
DISP: BA56-12EWA; BX56-12
IC1: MC34063AD; SOIC8
IC2: Atmega8a; TQFP32-08
IC3: TL431; SOT23
IRLU2905: LR2905; TO252
J1: 12-24V; SPC4077
L1: 220uH/250mA; L4532P
L2: 220uH; SM-B5
LED1: RED; CHIP-LED0805
LED2: GREEN; CHIP-LED0805
LM2904: LM358D; SO08
ON-OFF_HEAT: JP1Q; JP1
R1: 470R; R0805
R2: 10K; R0805
R3: 27R; R0805
R4: 2.2K-4.7K; R0805
R5: 20K; R0805
R6: 100K; R0805
R7: 100R; B25P
R8, R9: 7.5K; R0805
R10, R11: 3.3K; R0805
R12: 150K; R0805
R13: 1k; R0805
R14: 3K; R0805
R15: 1R; R0805
R16, R17, R18, R19, R20, R21, R22, R23: 510R; R0805
R24: 360R; R0805
R25, R26: 560R; R0805
SV1: SPI; ML6
SW1: EC12E_SW; ALPS_EC12E_SW
T1: BC846; SOT23
X1: PS2; M_DIN6

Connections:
+5V: C3.1, C4.+, C7.+, C14.+, D1.A, L1.2, L2.1, LM2904.8 (V+), R3.2, R10.1, R11.1, R14.1, R24.1, T1.3 (C)
BUZ: BUZZER_5V_GEN.- (2), IC2.12 (PB0(ICP1))
GND: C2.2, C3.2, C4.-, C5.-, C6.2, C7.-, C8.-, C9.-, C11.1, C12.2, C13.1, C14.-, D2.A, IC1.4 (GND), IC2.3 (GND), IC2.5 (GND), IC2.21 (AGND), IC3.3 (A), IRLU2905.3 (S), J1.1, J1.2, LED1.C, LED2.C, LM2904.4 (V-), LM2904.5 (+IN), R1.1, R2.1, R6.2, R7.E, R7.S, R13.1, SV1.6, SW1.C, SW1.D (1), X1.1, X1.2, X1.5, X1.SH1 (PE1), X1.SH2 (PE2), X1.SH3 (PE3)
HTR+: C1.1, C5.+, C8.+, IC1.6 (VCC), J1.3, R15.2, X1.6
HTR-: C1.2, IRLU2905.4 (D), X1.3
M15_MOSI: IC2.15 (PB3(MOSI/OC2)), R23.2, SV1.4
M16_MISO: IC2.16 (PB4(MISO)), R20.2, SV1.1
M17_SCK: IC2.17 (PB5(SCK)), R19.2, SV1.3
MEGA1: IC2.1 (PD3(INT1)), SW1.B
MEGA2: DISP.9 (CA), IC2.2 (PD4(T0/XCK))
MEGA7: DISP.12 (CA), IC2.7 (PB6(XTAL1/TOSC1))
MEGA8: IC2.8 (PB7(XTAL2/TOSC2)), R16.2
MEGA9: IC2.9 (PD5(T1)), R21.2
MEGA10: IC2.10 (PD6(AIN0)), R17.2
MEGA11: IC2.11 (PD7(AIN1)), R22.2
MEGA14: IC2.14 (PB2(SS/OC1B)), R18.2
MEGA25: IC2.25 (PC2(ADC2)), R26.2
MEGA26: IC2.26 (PC3(ADC3)), R25.2
MEGA30: IC2.30 (PD0(RXD)), SW1.E (2)
MEGA31: DISP.8 (CA), IC2.31 (PD1(TXD))
MEGA32: IC2.32 (PD2(INT0)), SW1.A
unnamed: DISP.11 (A), R16.1
unnamed: LED1.A, R25.1
unnamed: DISP.7 (B), R17.1
unnamed: DISP.4 (C), R18.1
unnamed: C9.+, IC2.20 (AREF), IC3.1 (C), IC3.2 (R), R24.2
unnamed: LM2904.1 (OUT), R5.2, R12.2
unnamed: LM2904.6 (-IN), LM2904.7 (OUT)
unnamed: LM2904.2 (-IN), R9.2, R12.1
unnamed: R7.A, R9.1, R10.2
unnamed: IRLU2905.1 (G), R1.2, T1.2 (E)
unnamed: C2.1, LM2904.3 (+IN), R6.1, R8.2
unnamed: DISP.2 (D), R19.1
unnamed: R2.2, R4.2, T1.1 (B)
unnamed: DISP.1 (E), R20.1
unnamed: LED2.A, R26.1
unnamed: BUZZER_5V_GEN.+ (1), R3.1
unnamed: ON-OFF_HEAT.2, R4.1
unnamed: IC1.5 (FB), R13.2, R14.2
unnamed: DISP.10 (F), R21.1
unnamed: DISP.5 (G), R22.1
unnamed: DISP.3 (DP), R23.1
unnamed: IC1.1 (SWC), IC1.7 (IS), IC1.8 (DC), R15.1
unnamed: C13.2, IC2.18 (AVCC), L2.2
unnamed: D2.C, IC1.2 (SWE), L1.1
unnamed: C6.1, IC1.3 (TC)
P_VCC: C12.1, D1.C, IC2.4 (VCC), IC2.6 (VCC), SV1.2
RST: IC2.29 (PC6(/RESET)), SV1.5
SH: IC2.13 (PB1(OC1A)), ON-OFF_HEAT.1
STSO: C11.2, IC2.23 (PC0(ADC0)), R5.1
TSIN+: R8.1, R11.2, X1.8

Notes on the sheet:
R7 подбор 40-63 Ом равно сопротивлению т.резистора паяльника при комнатной t=22С минус 3-5 Ом
+5V
+24v
отключение нагрева жала для калибровки температуры резистором R7
R4 Зависит от операционного усилителя

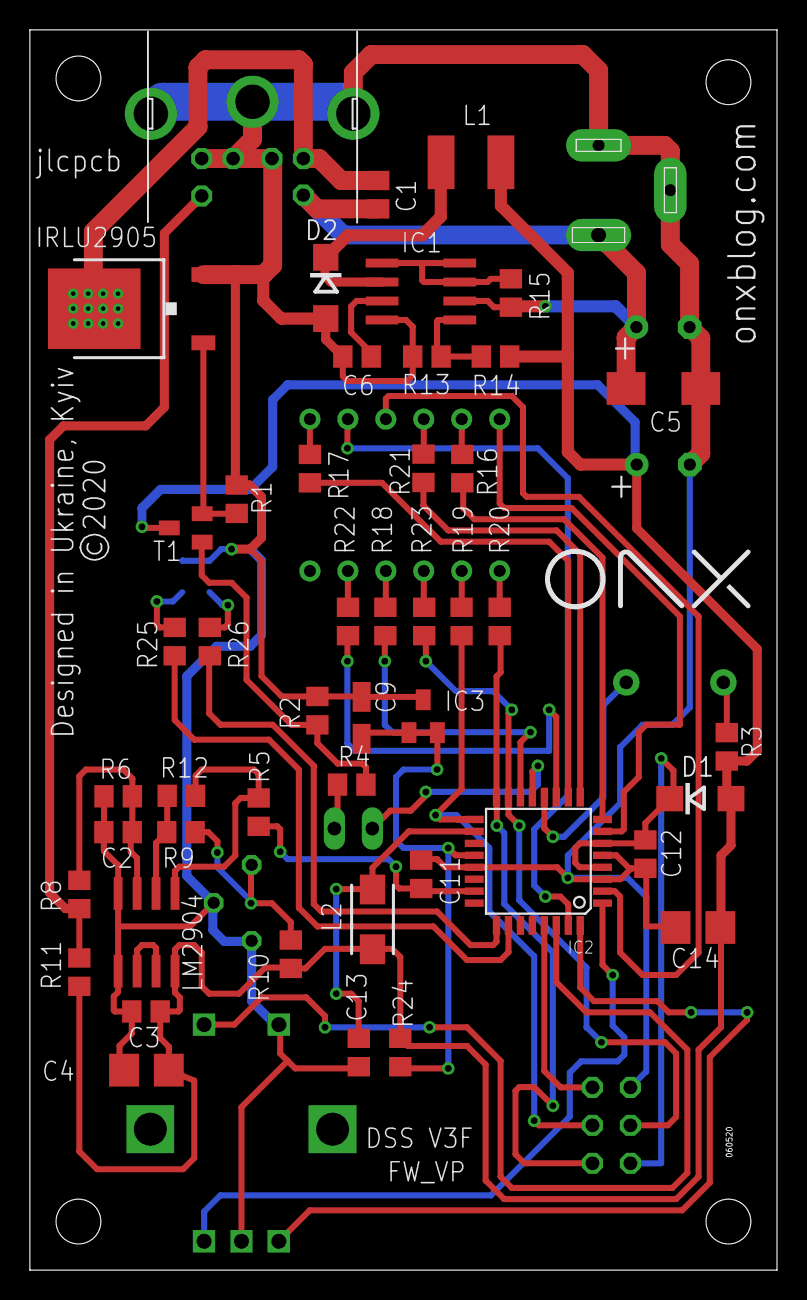
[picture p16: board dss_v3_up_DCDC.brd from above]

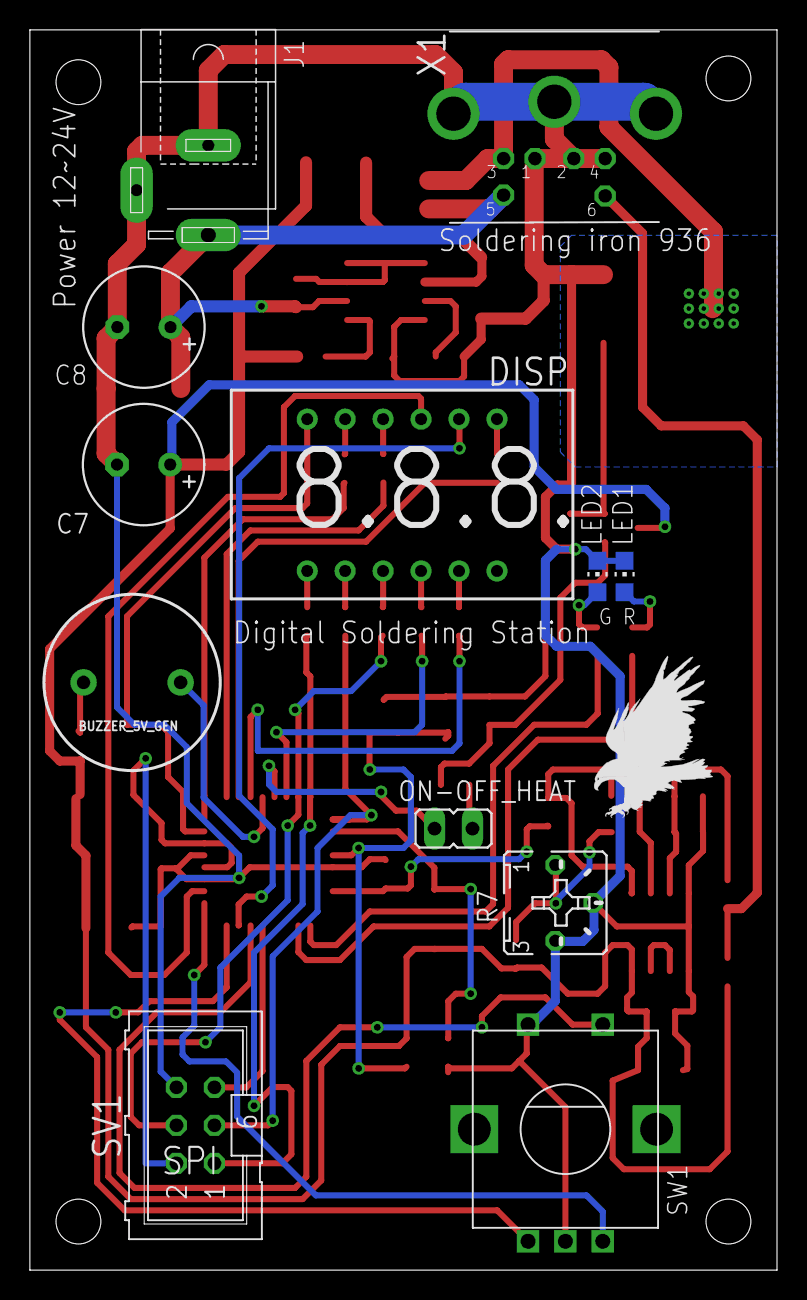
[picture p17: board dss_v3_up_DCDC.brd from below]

Board: 2 copper layers, 50.0 x 83.0 mm, 60 parts (13 on the bottom side), 51 nets.

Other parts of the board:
U$2: ONX
U$3: EAGLE-PLC-8MM

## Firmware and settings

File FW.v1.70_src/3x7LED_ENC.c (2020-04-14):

/*****************************************************
This program was produced by the
CodeWizardAVR V2.05.0 Professional
Automatic Program Generator
© Copyright 1998-2010 Pavel Haiduc, HP InfoTech s.r.l.
http://www.hpinfotech.com

Project : Soldering station 3x7LED ENC
Version : 1.70
Date    : 14.09.2014
Author  : Victor Poteraylo
Company : 
Comments: 20.08.2013


Chip type               : ATmega8
Program type            : Application
AVR Core Clock frequency: 8,000000 MHz
Memory model            : Small
External RAM size       : 0
Data Stack size         : 256
*****************************************************/

typedef unsigned char byte;

#include <mega8.h>
#include <delay.h>

#include <3x7LED_ENC.h>
#include <ADC.c>
#include <TC.c>

void main(void)
{
// Input/Output Ports initialization
// Port B initialization
// Function: Bit7=Out Bit6=Out Bit5=Out Bit4=Out Bit3=Out Bit2=Out Bit1=Out Bit0=Out 
DDRB=(1<<DDB7) | (1<<DDB6) | (1<<DDB5) | (1<<DDB4) | (1<<DDB3) | (1<<DDB2) | (1<<DDB1) | (1<<DDB0);
// State: Bit7=0 Bit6=0 Bit5=0 Bit4=0 Bit3=0 Bit2=0 Bit1=0 Bit0=1 
PORTB=(0<<PORTB7) | (0<<PORTB6) | (0<<PORTB5) | (0<<PORTB4) | (0<<PORTB3) | (0<<PORTB2) | (0<<PORTB1) | (1<<PORTB0);

// Port C initialization
// Function: Bit6=In Bit5=In Bit4=In Bit3=Out Bit2=Out Bit1=Out Bit0=In 
DDRC=(0<<DDC6) | (0<<DDC5) | (0<<DDC4) | (1<<DDC3) | (1<<DDC2) | (1<<DDC1) | (0<<DDC0);
// State: Bit6=T Bit5=T Bit4=T Bit3=0 Bit2=0 Bit1=0 Bit0=T 
PORTC=(0<<PORTC6) | (0<<PORTC5) | (0<<PORTC4) | (0<<PORTC3) | (0<<PORTC2) | (0<<PORTC1) | (0<<PORTC0);

// Port D initialization
// Function: Bit7=Out Bit6=Out Bit5=Out Bit4=Out Bit3=In Bit2=In Bit1=Out Bit0=In 
DDRD=(1<<DDD7) | (1<<DDD6) | (1<<DDD5) | (1<<DDD4) | (0<<DDD3) | (0<<DDD2) | (1<<DDD1) | (0<<DDD0);
// State: Bit7=0 Bit6=0 Bit5=0 Bit4=0 Bit3=P Bit2=P Bit1=0 Bit0=P 
PORTD=(0<<PORTD7) | (0<<PORTD6) | (0<<PORTD5) | (0<<PORTD4) | (1<<PORTD3) | (1<<PORTD2) | (0<<PORTD1) | (1<<PORTD0);

// External Interrupt(s) initialization
// INT0: Off
// INT1: Off
MCUCR=0x00;

// USART initialization
// USART disabled
UCSRB=0x00;

// Analog Comparator initialization
// Analog Comparator: Off
// Analog Comparator Input Capture by Timer/Counter 1: Off
ACSR=0x80;
SFIOR=0x00;

// SPI initialization
// SPI disabled
SPCR=0x00;

// TWI initialization
// TWI disabled
TWCR=0x00;

// Watchdog Timer initialization
// Watchdog Timer Prescaler: OSC/1024k
#pragma optsize-
WDTCR=0x1E;
WDTCR=0x0E;
#ifdef _OPTIMIZE_SIZE_
#pragma optsize+
#endif

//Startup init-----------------------------------
    ADCinit();                                  //ініціалізація АЦП
    TCinit();                                   //Ініціалізація таймерів-лічильників
    
    DispCmn = eDispCmn;                         //встановлюєм значення CA/CC з eeprom
    if (DispCmn == 255)
    {
        AutoSetDisp();
        StMode = SM_iDISP;
    }
    
    riTP = eiTP;                                //значення індексу пресета температури в ОЗУ
    InitTemp();
    
    r_tval = e_tval;                            //значення таймера в ОЗУ
    
    ADLdp = eADLdp;
    if (ADLdp) PwrTmRstEn = 1;
    else PwrTmRstEn = 0;
//    ADLdp_thr = MIN_ADLP + ADLdp;

    Ks = eKs;
    Kg = eKg;

    #asm("sei")
    
    if (BT_OK)
    {
        if (StMode == SM_iDISP) StMode = SM_iD_SP;  //режим підтвердження автовибору типа дисплея та початкових установок
        else StMode = SM_SUP;                       //режим SetUP
        
        DotDisp = 1;                            //Точка в першому розряді
        ReCode(NumVer,3);                       //Показуєм номер версії
        beep(250);
        
        while (BT_OK) {};                       //ждать поки нажата кнопка
        KeyPress = 0;                           //скидаєм стан OK_LNG
        delay_ms(250);
        KeyPress = 0;                           //скидаєм стан OK_SHT
        
        isChng = 1;                             //відбулась зміна значення
        m_delay = 4*CPS0_S;                     //затримка поточного режиму
        
        DotDisp = 0;
    }
    else if (StMode != SM_iDISP) StartUp();
    
    //------------------------------------------------------------
    while (1)
    {
        //---Encoder&KEY------------------------------------------
        if (!KeyPress) KeyPress = GetStateEncoder();
        if (KeyPress)
        {
            if (StMode == SM_STB || StMode == SM_OFF)
            {
                KeyPress = KEY_TIMER;
                beep(50);
                //isSS = 1;
            }
            if (TimerEn) TimerReset();
        }
        if (StMode == KEY_TIMER && KeyPress) KeyPress = KEY_TIMER;

        switch (KeyPress)                                   //обробка клавіш по їх функціях
        {
            case ENC_L:                                     //Minus
            {
                isChng = 1;                                 //відбулась зміна значення
                m_delay = 5*CPS0_S;                         //затримка поточного режиму 5sec
                BlinkDelay = CPS0_S/4;                      //затримка мигання 0.25sec
                switch (StMode)
                {
                    case SM_MAIN_PRM:
                    case SM_MAIN_SEC:
                    {
                        m_delay = 4*CPS0_S;                 //затримка поточного режиму 4sec
                        if (((StMode == SM_MAIN_PRM)&&(ePCM == PCM_TEMP))||((StMode == SM_MAIN_SEC)&&(ePCM == PCM_PRST)))
                        {
                            if (!chDispMode)
                            {
                                DispVal = SetTemp;
                                chDispMode = 1;
                            }
                            if (DispVal > MIN_TEMP) DispVal -= 5;   //температура на екрані більша за мінімальну то зменшуємо її
                            else beep(50);
                        }
                        else if (((StMode == SM_MAIN_PRM)&&(ePCM == PCM_PRST))||((StMode == SM_MAIN_SEC)&&(ePCM == PCM_TEMP)))
                        {
                            StMode = SM_WAIT_STB;
                        }
                        break;
                    };
                    case SM_WAIT_STB:
                    case SM_WAIT_OFF:
                    {
                        m_delay = 4*CPS0_S;
                        if (StMode == SM_WAIT_OFF) beep(50);
                        StMode = SM_WAIT_OFF;
                        break;
                    };
                    case SM_TMR_SET:                        //режим встановлення значення таймера
                    {
                        m_delay = 4*CPS0_S;                 //затримка поточного режиму 4sec
                        if (DispVal) DispVal -= 5;
                        else beep(50);
                        break;
                    };
                    case SM_SUP:                            //режим настройки
                    {
                        StMode = SM_HSM;
                        break;
                    };
                    case SM_CLB:                            //калібровка
                    case SM_HSM:
                    case SM_ADL:                            //детектор активності паяльника
                    case SM_CTRL:
                    case SM_SBT:
                    {
                        if (StMode == SM_CLB) StMode = SM_SBT;
                        else StMode -= 2;
                        break;
                    };
                    case SM_CLB_SET:
                    {
                        switch (ClbMode)
                        {
                            case CLM_LPT:
                            {
                                if (clb_ct_val) clb_ct_val--;
                                else beep(50);
                                break;
                            };
                            case CLM_HPT:
                            {
                                if (clb_ct_val > (CLB_TOP - 100)) clb_ct_val--;
                                else beep(50);
                                break;
                            };
                        }
                        break;
                    };
                    case SM_HSM_SET:
                    case SM_ADL_SET:
                    {
                        if (DispVal) DispVal--;
                        else beep(50);
                        break;
                    };
                    case SM_SBT_SET:
                    {
                        if (DispVal > MIN_TEMP) DispVal -= 5;
                        else beep(50);
                        break;
                    };
                    case SM_CTRL_SET:
                    {
                        switch (SubMnuMode)
                        {
                            case CTRL_PCM:
                            {
                                if (DispVal) DispVal = PCM_TEMP;
                                else DispVal = PCM_PRST;
                                break;
                            };
                            case CTRL_NOP:
                            {
                                if (DispVal > MIN_PRN) DispVal--;
                                else beep(50);
                                break;
                            };
                        }
                        break;
                    };
                    case SM_iDISP:
                    case SM_iD_SP:
                    {
                        if (DispCmn == CAD) DispCmn = CCD;  //CC
                        else DispCmn = CAD;                 //CA
                        break;
                    };
                }
                KeyPress = 0;                               //скидаєм значення нажатої клавіші
                break;
            };
                
            case ENC_R:                                     //Plus - все аналогічно "мінусу"
            {
                isChng = 1;
                m_delay = 5*CPS0_S;
                BlinkDelay = CPS0_S/4;                      //затримка мигання 0.25sec
                switch (StMode)
                {
                    case SM_MAIN_PRM:
                    case SM_MAIN_SEC:
                    {
                        m_delay = 4*CPS0_S;                 //затримка поточного режиму 4sec
                        if (((StMode == SM_MAIN_PRM)&&(ePCM == PCM_TEMP))||((StMode == SM_MAIN_SEC)&&(ePCM == PCM_PRST)))
                        {
                            if (!chDispMode)
                            {
                                DispVal = SetTemp;
                                chDispMode = 1;
                            }
                            if (DispVal < MAX_TEMP) DispVal += 5;
                            else beep(50);
                        }
                        else if (((StMode == SM_MAIN_PRM)&&(ePCM == PCM_PRST))||((StMode == SM_MAIN_SEC)&&(ePCM == PCM_TEMP)))
                        {
                            if (riTP == eNP-1) riTP = 0;
                            else riTP++;
                            DispVal = eTP[riTP];
                        }
                        break;
                    };
                    case SM_WAIT_STB:
                    case SM_WAIT_OFF:
                    {
                        m_delay = 4*CPS0_S;                 //затримка поточного режиму 4sec
                        DispVal = eTP[riTP];
                        if (ePCM == PCM_TEMP) StMode = SM_MAIN_SEC;
                        else StMode = SM_MAIN_PRM;
                        break;
                    };                    
                    case SM_TMR_SET:
                    {
                        m_delay = 4*CPS0_S;                 //затримка поточного режиму 4sec
                        if (DispVal < MAX_TIMER) DispVal += 5;
                        else beep(50);
                        break;
                    };
                    case SM_SUP:
                    {
                        StMode = SM_ADL; 
                        break;
                    };
                    case SM_CLB:                            //калібровка
                    case SM_HSM:
                    case SM_ADL:                            //детектор активності паяльника
                    case SM_CTRL:
                    case SM_SBT:                    
                    {
                        if (StMode == SM_SBT) StMode = SM_CLB;
                        else StMode += 2;
                        break;
                    };
                    case SM_CLB_SET:
                    {
                        switch (ClbMode)
                        {
                            case CLM_LPT:
                            {
                                if (clb_ct_val < 50) clb_ct_val++;
                                else beep(50);
                                break;
                            };
                            case CLM_HPT:
                            {
                                if (clb_ct_val < (CLB_TOP + 100)) clb_ct_val++;
                                else beep(50);
                                break;
                            };
                        }
                        break;
                    };
                    case SM_HSM_SET:
                    {
                        switch (SubMnuMode)
                        {
                            case HSM_KPS:
                            case HSM_KIS:
                            case HSM_KDS:
                            {
                                if (DispVal < 99) DispVal++;
                                else beep(50);
                                break;
                            };
                            case HSM_PFS:
                            {
                                if (!DispVal) DispVal = 1;
                                else beep(50);
                                break;
                            };
                            case HSM_MPS:
                            {
                                if (DispVal < MaxPWM) DispVal++;
                                else beep(50);
                                break;
                            };
                        }
                        break;
                    };
                    case SM_ADL_SET:
                    {
                        if (DispVal < 95) DispVal++;
                        else beep(50);
                        break;
                    };
                    case SM_SBT_SET:
                    {
                        if (DispVal < MAX_TEMP) DispVal += 5;
                        else beep(50);
                        break;
                    };
                    case SM_CTRL_SET:
                    {
                        switch (SubMnuMode)
                        {
                            case CTRL_PCM:
                            {
                                if (DispVal) DispVal = PCM_TEMP;
                                else DispVal = PCM_PRST;
                                break;
                            };
                            case CTRL_NOP:
                            {
                                if (DispVal < MAX_PRN) DispVal++;
                                else beep(50);
                                break;
                            };
                        }
                        break;
                    };
                    case SM_iDISP:
                    case SM_iD_SP:
                    {
                        if (DispCmn == CAD) DispCmn = CCD;  //CC
                        else DispCmn = CAD;                 //CA
                        break;
                    };
                }
                KeyPress = 0;
                break;
            };
                
            case OK_SHT:                        //Ok short
            {
                if (LngKeyPress)                                //якщо було жовге натискання
                {
                    LngKeyPress = 0;                            //скидання довгого утримування кнопки
                                                                //(блокування короткого натискання при відпусканні довгого)
                    KeyPress = 0;                               //скидання функції натиснутої кнопки
                    break;
                }
                switch (StMode)
                {
                    case SM_MAIN_PRM:
                    {
                        m_delay = 4*CPS0_S;     //затримка виходу з поточного режиму    4sec
                        isChng = 2;
                        if (ePCM == PCM_TEMP) DispVal = eTP[riTP];
                        else DispVal = SetTemp;
                        StMode = SM_MAIN_SEC;
                        beep(50);
                        break;
                    };
                    case SM_MAIN_SEC:
                    {
                        m_delay = 4*CPS0_S;     //затримка виходу з поточного режиму    4sec
                        //isChng = 2;             //перехід в інший режим
                        if ((eiTP != riTP) || ((SetTemp != DispVal) && isChng == 1))
                        {
                            if (ePCM == PCM_TEMP)
                            {
                                #asm("cli")
                                eiTP = riTP;
                                eLastT = 0;
                                #asm("sei")
                            }
                            else
                            {
                                #asm("cli")
                                eLastT = DispVal;
                                #asm("sei")
                            }
                            SetTemp = DispVal;
                        }
                        //isChng = 1;
                        StMode = SM_TMR_SET;    //переходим в режим налаштування теймера
                        DispVal = e_tval;
                        beep(50);
                        break;
                    };
                    case SM_TMR_SET:            //режим налаштування теймера
                    {
                        if (isChng)
                        {
                            r_tval = DispVal;
                            TimerInit();
                        }
                        m_delay = 0;            //0sec
                        beep(50);
                        break;
                    };
                    case SM_CLB:
                    {
                        ClbInit();
                        break;
                    };
                    case SM_CLB_SET:
                    {
                        switch (ClbMode)
                        {
                            case CLM_LPT:
                            {
                                ClbMode = CLM_LPT_OK; 
                                break;
                            };
                            case CLM_HPT:
                            {
                                ClbMode = CLM_HPT_OK;
                                break;
                            };
                        }
                        break;
                    };
                    case SM_HSM:
                    {
                        m_delay = 5*CPS0_S;                     //затримка виходу з поточного режиму    5sec
                        isChng = 1;
                        StMode = SM_HSM_SET;
                        SubMnuMode = HSM_KPS;
                        DispVal = eHSM[0];                      //значення Kp
                        beep(50);
                        break;
                    };
                    case SM_HSM_SET:
                    {
                        m_delay = 5*CPS0_S;                     //затримка виходу з поточного режиму    5sec
                        isChng = 1;
                        switch (SubMnuMode)
                        {
                            case HSM_KPS:                       //установка Kp
                            {
                                if (DispVal != eHSM[0])
                                {
                                    #asm("cli")
                                    eHSM[0] = DispVal;
                                    #asm("sei")
                                }
                                SubMnuMode = HSM_KIS;           //установка Ki
                                DispVal = eHSM[1];
                                break;
                            };
                            case HSM_KIS:                       //установка Ki
                            {
                                if (DispVal != eHSM[1])
                                {
                                    #asm("cli")
                                    eHSM[1] = DispVal;
                                    #asm("sei")
                                }
                                SubMnuMode = HSM_KDS;           //установка Kd
                                DispVal = eHSM[2];
                                break;
                            };
                            case HSM_KDS:                       //установка Kd
                            {
                                if (DispVal != eHSM[2])
                                {
                                    #asm("cli")
                                    eHSM[2] = DispVal;
                                    #asm("sei")
                                }
                                SubMnuMode = HSM_PFS;           //вибір частоти ШІМ
                                DispVal = eHSM[3];
                                break;
                            };
                            case HSM_PFS:
                            {
                                if (DispVal != eHSM[3])
                                {
                                    #asm("cli")
                                    eHSM[3] = DispVal;
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

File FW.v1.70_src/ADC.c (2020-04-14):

//

#include <ADC.h>

//ADMUX:
    //REFS1:0 - Reference Selection Bits
        //00 AREF, Internal Vref turned off
        //01 AVCC with external capacitor at AREF pin
        //10 Reserved
        //11 - Internal 2.56V Voltage Reference with external capacitor at AREF pin
    //ADLAR - ADC Left Adjust Result
    //MUX3:0 - Analog Channel Selection Bits
        //0000 - ADC0

//ADCSRA:
    //ADEN - ADC Enable
    //ADSC - ADC Start Conversion
    //ADFR - ADC Free Running Select
    //ADIF - ADC Interrupt Flag
    //ADIE - ADC Interrupt Enable
    //ADPS2:0 - ADC Prescaler Select Bits
        //110 - Division Factor 64

//ADCH, ADCL Conversion result (ADCW)

//--------------------------------------------------------------------
interrupt [ADC_INT] void ADCCmpl(void)
{
    getADC();
//PORTC.1 = 0;
}

//--------------------------------------------------------------------
void ADCinit (void)
{
    // ADC initialization
    // ADC Clock frequency: 125,000 kHz
    // ADC Voltage Reference: AREF pin
    // ADC Input 0
    //ADMUX = (0<<REFS1)|(0<<REFS0)|(0<<ADLAR)|(0<<MUX3)|(0<<MUX2)|(0<<MUX1)|(0<<MUX0);
    ADMUX = 0x00;
    //ADCSRA = (1<<ADEN)|(0<<ADSC)|(0<<ADFR)|(1<<ADIF)|(1<<ADIE)|(1<<ADPS2)|(1<<ADPS1)|(0<<ADPS0);
    ADCSRA = 0b10011110;
}

//--------------------------------------------------------------------
void getADC(void)
{
    static int FirADC[4];
    static byte i = 0;
    
    //FIR filter for ADC
    ADCVal = ADCVal - FirADC[i] + ADCW;
    FirADC[i] = ADCW;
    if (++i == 4) i = 0;
}

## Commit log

2020-04-14 DSS_v3
    First push
    [dss_v3.brd, dss_v3.sch]
2020-04-29 gnd fix add smd capacitor for select
    [dss_v3_up_DCDC.brd, dss_v3_up_DCDC.sch]

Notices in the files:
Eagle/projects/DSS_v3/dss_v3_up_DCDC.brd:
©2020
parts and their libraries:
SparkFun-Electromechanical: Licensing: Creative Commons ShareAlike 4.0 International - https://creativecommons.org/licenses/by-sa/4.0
